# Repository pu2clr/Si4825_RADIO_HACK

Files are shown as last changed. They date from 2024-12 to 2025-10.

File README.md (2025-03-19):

# Si4825 RADIO HACK

This project aims to assist individuals interested in developing or modifying receivers based on the Si4825. It focuses on converting AM/FM radios equipped with the Si4825 DSP to enable shortwave (SW) reception, as well as expanding the shortwave bands on existing AM/FM/SW receivers. By modifying and enhancing the circuitry, this documentation and project provide guidance on expanding the functionality of these radios, allowing them to receive a broader range of frequencies. By understanding the documentation presented in this repository, you are also expected to be capable of developing your own receiver using the Si4825 and a few additional components.

***One of the highlights of this documentation is to unlock new capabilities in receivers based on the Si4825, providing a practical and accessible way to upgrade and customize low-cost AM/FM radios for shortwave listening.*** 

As suggested before, this repository will serve as a guide for the construction, modification, and improvement of Si4825-based receivers, offering insights into hardware adjustments and software tweaks when applicable. ***Some of the modifications presented here will suggest replacing the Si4825 with the Si4827 - essentially the same DSP, but with additional features that allow for the integration of a microcontroller such as the ATmega328 (Arduino), ESP32, ESP8266, STM32, among others***. Integrating a microcontroller into a radio project involving this DSP series can enhance the user interface by adding buttons and a display to control the receiver.

Author: Ricardo Lima Caratti - Jan, 2025

## Summary

1. [Technical Characteristics of the Si4825](https://github.com/pu2clr/Si4825_RADIO_HACK?tab=readme-ov-file#the-si4825-pinout)
2. [Converting a $5 KapBom (K-2019) AM/FM Analog Radio into a Digital and Shortwave Radio](https://github.com/pu2clr/Si4825_RADIO_HACK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)
3. [Converting a $10 KapBom (KA-3196) AM/FM/SW Analog Radio into a Digital Radio with Extended Shortwave Bands]()
4. [Restoring a Motobras RM-PFT73AC Radio (made in Brazil) into a Digital Radio with FM and Enhanced Shortwave Capabilities]()

## ATTENTION

***Any modifications or interventions you make to your radio - including those equipped with the Si4825 DSP - come with the risk of causing irreparable damage. If you decide to attempt any of the procedures described in this project, please understand that you are doing so at your own risk.***

***The author of this project assumes no responsibility for any damage that may occur to your radio as a result of following the instructions or suggestions provided here.***

***Proceed with caution and ensure you are fully aware of the potential consequences before making any modifications.***

***The tests and observations conducted by the author refer to the SI4825-A10 and SI4825-A20 versions.***

## The Si4825 pinout

To build a radio based on the Si4825 or even modify a commercial radio, it is essential to know the functions of its pins. The following figure presents the pin configuration of the Si4825.

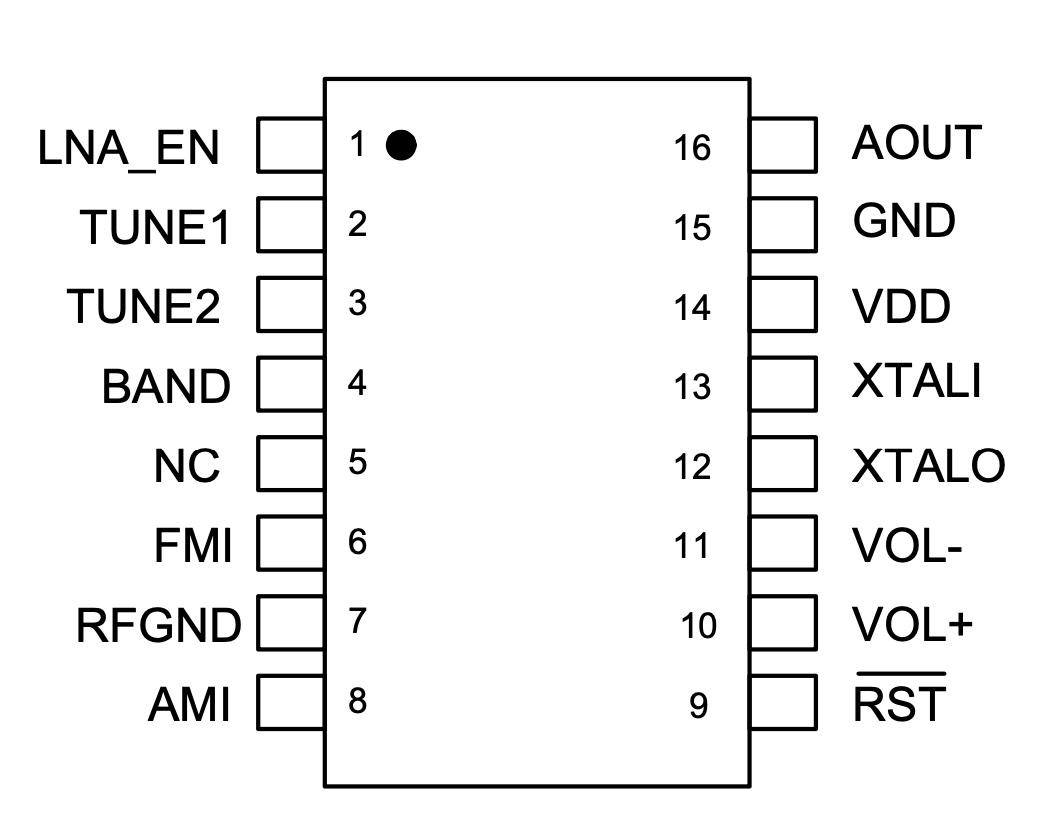
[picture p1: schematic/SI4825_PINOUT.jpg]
The Si4825 pinout


| Pin # | Name | Description |
| ----- | --- | --- |
| 1 | LNA_EN | Enable SW external LNA - Wide or Narrow band - See band table |
| 2 | TUNE1 | Frequency tuning - Connected to the 100K  potentiometer | 
| 3 | TUNE2 | Frequency tuning -  Connected to the 100K  potentiometer |
| 4 | BAND | Band selection -  connected to voltage divider  / band selector |
| 5 | NC | No connect. Leave floating |
| 6 | FMI | FM RF inputs. FMI should be connected to the antenna trace |
| 7 | RFGND | RF ground. Connect to ground plane on PCB |
| 8 | AMI | AM RF input. AMI should be connected to the AM antenna |
| 9 | RST | Device reset (active low) input |
| 10 | VOL+ | Volume button up |
| 11 | VOL- | Volume button down |
| 12 | XTALO | Crystal oscillator output |
| 13 | XTALI | Crystal oscillator input/external reference clock input |
| 14 | VDD | Supply voltage. May be connected directly to battery |
| 15 | GND | Ground. Connect to ground plane on PCB |
| 16 | AOUT | Audio output |

## SI4825 BAND SETUP

The Si4825 is a basic digital AM/FM/SW radio receiver chip that uses mechanical tuning. It handles everything from the antenna input to the audio output, making it a complete radio receiver solution.

This chip is part of Silicon Laboratories' family of multi-band tuners and makes it easier to add radio reception to audio devices. It is small, requires fewer components, and offers proven, high-performance results.

The Si4825 needs only a simple circuit to work and does not require manual tuning during manufacturing. It uses Silicon Labs' patented digital low-intermediate frequency (low-IF) technology, providing good signal reception and interference rejection for AM, FM, and shortwave (SW) bands.

Because the chip is highly integrated and fully tested at the factory, it makes the design process easier, improves overall system quality, and simplifies manufacturing.

**IMPORTANT:** In some contexts within the Si4825 documentation, the acronym AM refers to Medium Wave (MW) rather than Amplitude Modulation. However, it is important to highlight that both MW and SW bands operate using Amplitude Modulation. 

## Frequency Tuning 

A valid channel can be found by adjusting a 100K potentiometer connected to the TUNE1 and TUNE2 pins of the Si4825 chip. The central terminal of the potentiometer is connected to the TUNE2 pin, while the other terminals are connected to TUNE1 and ground, respectively.

This configuration allows for smooth and precise frequency tuning across the supported bands.

### Datasheet FM band information

The Si4825 has a built-in low noise amplifier (LNA) that allows it to receive FM radio signals from 64 to 109 MHz, covering the worldwide FM broadcast band. It can also pick up TV audio stations in the same frequency range used in China.

Pre-emphasis and de-emphasis are techniques used to improve the sound quality of FM radio by reducing high-frequency noise and interference.

When an FM station transmits a signal, it boosts the high audio frequencies using a pre-emphasis filter.
On the receiving end, FM radios use a de-emphasis filter to lower those high frequencies, bringing the sound back to normal.
Different regions use different de-emphasis settings. The de-emphasis filter can have a time constant of 50 or 75 microseconds (µs), depending on the area.

## Datasheet MW(AM) band information 

The Si4825 is a highly integrated radio receiver that can pick up AM (MW) signals from 504 to 1750 kHz across five sub-bands. It uses digital low-IF technology, requiring very few external components and no manual tuning during production.

This technology provides precise filtering, ensuring good selectivity and signal-to-noise ratio (SNR) with minimal variation across the entire AM band. **One of the five sub-bands, called AM4 (520-1730 kHz), is designed to work globally, supporting both 9 kHz and 10 kHz channel spacing to meet different regional AM standards**.

Just like with FM signals, the Si4825 enhances sensitivity and reduces interference from strong signals, making it easier to receive weaker stations.

The receiver is also flexible when it comes to antennas. It works with ferrite loop stick antennas ranging from 180 to 450 µH. If you want to use an air loop antenna, a transformer can be added to increase its inductance. By using a 1:5 turn ratio inductor, the inductance is multiplied by 25 times, making it compatible with most AM air loop antennas, which typically have inductance values between 10 and 20 µH.

## Datasheet SW(AM) information 

The Si4825 can receive signals from 36 shortwave (SW) bands ranging from 2.3 to 28.5 MHz. Of these, 18 bands are narrow meter bands, while the remaining bands cover wider frequency ranges, making them suitable for shortwave radios that operate with one or two SW bands.

The Si4825 offers extensive shortwave capabilities with the advantage of requiring minimal external components and no factory adjustments. Additionally, the FM antenna can be used to receive shortwave signals, simplifying the design and reducing the need for extra components.

### Important Considerations for Shortwave Band Configuration on the Si4825

As shown in the table below, each of the 18 shortwave (SW) bands on the Si4825 can be configured in two modes: **'Wide Band'** or **'Narrow Band'**.  

The values of the resistor network **do not need to be changed** to switch between 'Wide' and 'Narrow'. This configuration is controlled by the state of **pin 1** on the Si4825:  

- If **pin 1** is pulled up to **VCC** using a **10K resistor**, the selected band will be **'Wide'**.  
- If **pin 1** is **floating (disconnected)**, the selected band will be **'Narrow'**.  

As a result, each shortwave band can have **two possible coverage ranges**. See the table below. 

| Band Name  | Band Frequency Range | Channel Space | AR(kΩ)| Note |
| --- | --- | ---| ----- | --- |
| | | | | 47kΩ botton resistor| 
| FM1 | 87-108 MHz (50 µs) | |  47 | | 
| FM2 | 87-108 MHz (50 µs) | |  57 | | 
| FM3 | 87-108 MHz (75 µs) | |  67 | |
| FM4 | 87-108 MHz (75 µs) | |  77 | |
| FM5 | 86.5-109 MHz (50 µs) | |  87 | |
| FM6 | 86.5-109 MHz (50 µs) | |  97 | |
| FM7 | 87.3-108.25 MHz (50 µs) | | 107 | | 
| FM8 | 87.3-108.25 MHz (50 µs) | | 117 | |
| FM9 | 87.3-108.25 MHz (75 µs) | | 127 | |
| FM10 | 87.3-108.25 MHz (75 µs) | | 137 | |
| FM11 | 76-90 MHz (50 µs) | | 147 | |
| FM12 | 76-90 MHz (50 µs) | | 157 | |
| FM13 | 64-87 MHz (50 µs) | | 167 | |
| FM14 | 64-87 MHz (50 µs) | | 177 | |
| FM15 | 76-108 MHz (50 µs) | | 187 | |
| FM16 | 76-108 MHz (50 µs) | | 197 | |
| FM17 | 64-108 MHz (50 µs) | | 207 | |
| FM18 | 64-108 MHz (50 µs) | | 217 | | 
| AM1 | 520-1710 kHz | 10k | 227 | |
| AM2 | 522-1620 kHz | 9k | 237 | |
| AM3 | 504-1665 kHz | 9k | 247 | | 
| AM4 | 522-1728 kHz/520-1730 kHz  | 9k / 10k | 257 | |
| AM5 | 510-1750 kHz | 10k | 267 | |
| SW1-Wide | 2.3-10.0 MHz | 5k | 277 | Pin 1 pulled up | 
| SW1-Narrow | 2.30-2.49 MHz | 5k | | Pin 1 **floating** |
| SW2-Wide | 3.2-7.6 MHz | 5k | 287 | Pin 1 pulled up |
| SW2-Narrow | 3.20-3.40 MHz | 5k | | Pin 1 **floating** | 
| SW3-Wide | 3.2-10.0 MHz | 5k | 297 | Pin 1 pulled up |
| SW3-Narrow | 3.90-4.00 MHz | 5k | | Pin 1 **floating** | 
| SW4-Wide | 3.7-12.5 MHz | 5k | 307 | Pin 1 pulled up | 
| SW4-Narrow | 4.75-5.06 MHz | 5k | | Pin 1 **floating** |
| SW5-Wide | 3.9-7.5 MHz | 5k | 317 | Pin 1 pulled up |
| SW5-Narrow | 5.6-6.4 MHz | 5k | | Pin 1 **floating** | 
| SW6-Wide | 3.2-10.0 MHz | 5k | 327 | Pin 1 pulled up |
| SW6-Narrow | 3.90-4.00 MHz | 5k | | Pin 1 **floating** | 
| SW7-Wide | 5.8-12.1 MHz | 5k | 337 | Pin 1 pulled up | 
| SW7-Narrow | 6.8-7.6 MHz | 5k | | Pin 1 **floating** |
| SW8-Wide | 5.9-9.50 MHz | 5k | 347 | Pin 1 pulled up |
| SW8-Narrow | 7.1-7.6 MHz | 5k | | Pin 1 **floating** | 
| SW9-Wide | 5.9-18.0 MHz | 5k | 357 | Pin 1 pulled up |
| SW9-Narrow | 9.2-10 MHz | 5k | | Pin 1 **floating** | 
| SW10-Wide  | 7.0-16.0 MHz | 5k | 367 | Pin 1 pulled up | 
| SW10-Narrow| 11.45-12.25 MHz | 5k | | Pin 1 **floating** |
| SW11-Wide  | 7.0-23.0 MHz | 5k | 377 | Pin 1 pulled up |
| SW11-Narrow| 11.6-12.2 MHz | 5k | | Pin 1 **floating** | 
| SW12-Wide  | 9.0-16.0 MHz | 5k | 387 | Pin 1 pulled up |
| SW12-Narrow| 13.4-14.2 MHz | 5k | | Pin 1 **floating** | 
| SW13-Wide  | 9.0-22.0 MHz | 5k | 397 | Pin 1 pulled up | 
| SW13-Narrow| 13.57-13.87 MHz | 5k | | Pin 1 **floating** |
| SW14-Wide  | 9.5-18.0 MHz | 5k | 407 | Pin 1 pulled up |
| SW14-Narrow| 15 -15.9 MHz | 5k | | Pin 1 **floating** | 
| SW15-Wide  | 10.0-16.0 MHz | 5k | 417 | Pin 1 pulled up |
| SW15-Narrow| 17.1 -18 MHz | 5k | | Pin 1 **floating** | 
| SW16-Wide  | 10.0-22.0 MHz | 5k | 427 | Pin 1 pulled up | 
| SW16-Narrow| 17.48-17.9 MHz | 5k | | Pin 1 **floating** |
| SW17-Wide  | 13.0-18.0 MHz | 5k | 437 | Pin 1 pulled up |
| SW17-Narrow| 21.2-22 MHz | 5k | | Pin 1 **floating** | 
| SW18-Wide  | 18.0-28.5 MHz | 5k | 447 | Pin 1 pulled up |
| SW18-Narrow| 21.45-21.85 MHz | 5k | | Pin 1 **floating** | 
| | | | 500 | 53kΩ top resistor | 

#### About the Previous Table:

* The **Botton Resistor** (first line - connected to GND) represents the minimum resistance required to reach the first band (FM1). 
* The **Top Resistor** (last line - connected to TUNE1) is the value needed to complete a total of 500K. Hypothetically, if you use all the bands described in the table, you should use a 53K resistor.
* AR(K) is the value of the accumulated resistance required to select the desired band. For example: Consider that the receiver you are designing only includes the SW 10 band. The value of the first resistor (top resistor) should be 367K, and the value of the second resistor (bottom resistor) should be 133K (500 - 367). The common point between the two resistors must be connected to pin 4 of the Si4825 (BAND).
* Pay attention to the SW bands and observe the Wide and Narrow configurations. The resistance value required to select the band does not change. The Wide or Narrow configuration is determined by pin 1 of the Si4825, as previously described.

#### About Narrow and Wide band setup

The Si4825 allows configuration between Wide Band and Narrow Band through pin 1 (LNA_EN). Frequency coverage for Wide and Narrow Band is detailed in the previous table.

In general, Wide Band is recommended when the goal is to provide the user with a broad frequency range, with limited band selection options on the receiver. While this approach allows for shortwave reception over a wide range, it can make locating and tuning to a specific station more challenging. To configure the receiver for Wide Band, simply add a 10kΩ pull-up resistor to the LNA_EN pin.

Conversely, if the radio design includes a multi-position band selection switch (six or more positions, for example), Narrow Band configuration may be more suitable. This option offers narrower coverage bands, providing a more precise tuning experience and making it easier to locate a specific station. For this configuration, the LNA_EN pin should be left floating (unconnected).

It is also possible to implement both options in the same design. To achieve this, add a switch that, when turned on, connects the pull-up resistor to the LNA_EN pin, and when turned off, leaves the pin floating. This will be addressed later with more details.

The images below show the dial examples of commertial receivers based on Si4825 using Narrow and Wide band setup. 

##### Narrow band commertial receiver dial 

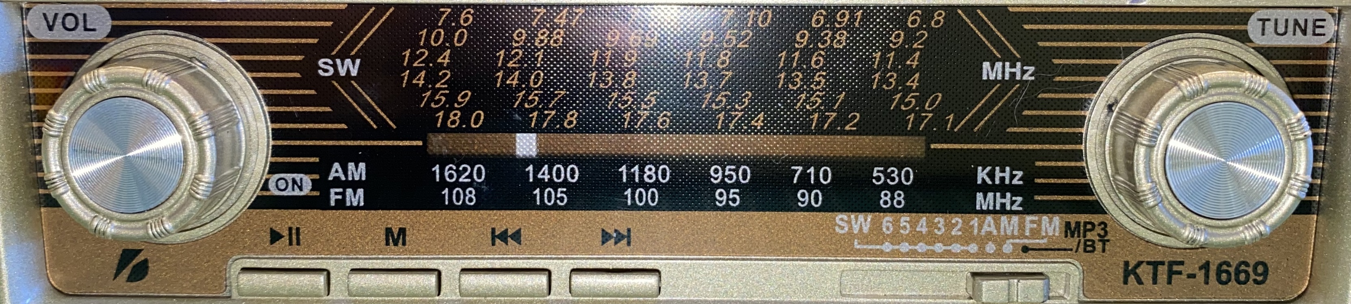
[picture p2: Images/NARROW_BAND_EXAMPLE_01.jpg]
Narrow band commertial receiver dial


Notice in the previous figure that the radio design divides the Shortwave bands into six segments: 6.8 to 7.6 MHz, 9.2 to 10.0 MHz, 11.4 to 12.4 MHz, 13.4 to 14.2 MHz, 15.0 to 15.9 MHz, and 17.1 to 18.0 MHz. This configuration requires a six-position band switch for Shortwave, plus one position for AM/MW and another for FM, totaling eight positions.

This design can provide a better station tuning experience. The narrower bands make it easier to locate and tune to a station compared to a 'Wide Band' design. Additionally, nearby stations broadcasting at the same time are easier to separate.

##### Wide band commertial receiver dial 

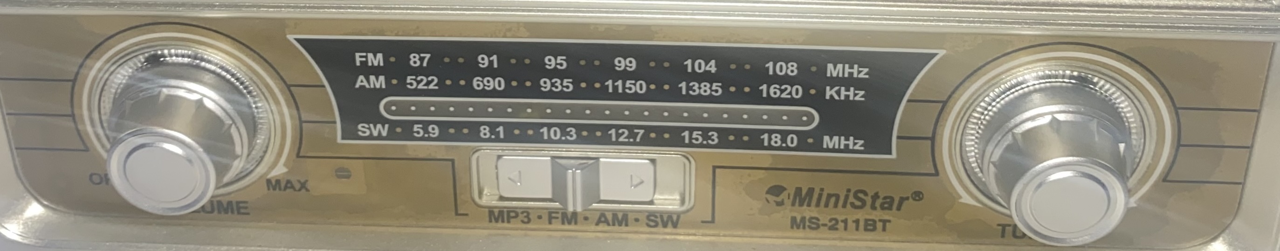
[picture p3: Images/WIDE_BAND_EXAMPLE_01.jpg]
Wide band commertial receiver dial


Notice on the dial shown in the previous figure that a single SW band covers from 5.9 to 18 MHz. This characteristic simplifies, to some extent, the radio design when adding the Shortwave band. However, this configuration may make it more difficult to tune stations, especially if the user wants to tune in to a station located among others nearby.

#### The circuit below shows the Narrow and Wide Band setup.  

Although not very common or typically found in commercial receivers based on the Si4825, it is possible to build a receiver that offers Narrow and Wide Band options. To achieve this, simply follow the circuit shown below.

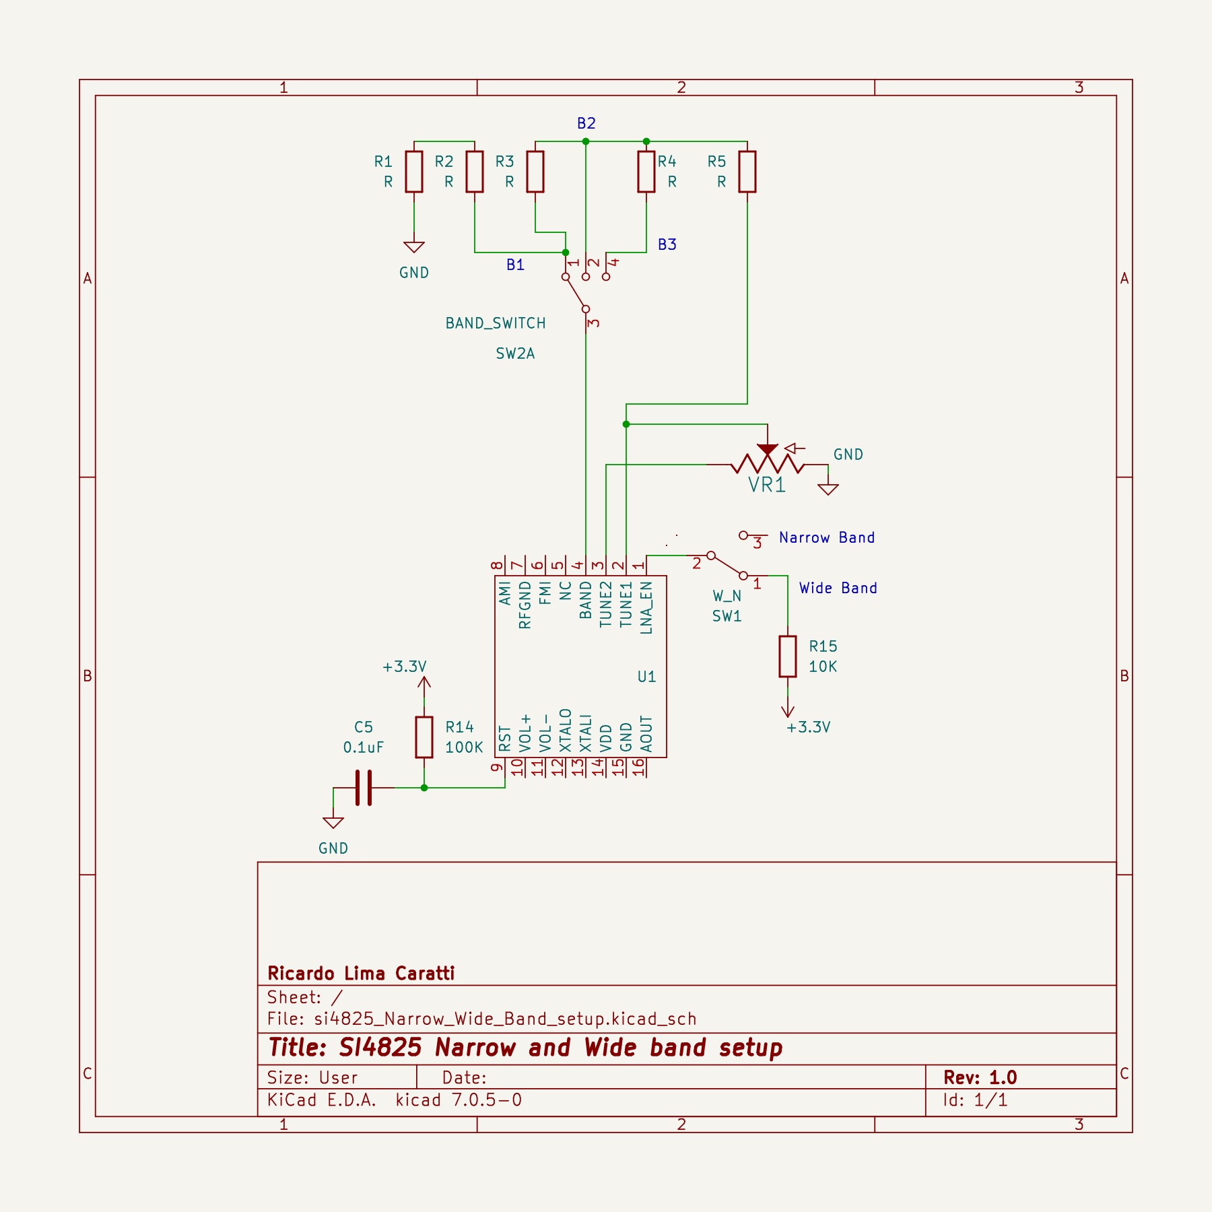
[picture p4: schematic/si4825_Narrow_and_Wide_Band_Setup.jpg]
About Narrow and Wide band setup


However, if you incorporate the previously mentioned tip regarding the Narrow and Wide Band configuration into the circuit, you can opt for 24 shortwave bands instead of 12. 

***Note: Changing the state of this switch does not immediately alter the configuration from Wide to Narrow (or vice-versa). For the change to take effect, the Si4825 must be reset or power-cycled.***

#### More About Pin 1 (LNA_EN) 

Under normal conditions, this pin stays in a high state (+Vcc) when the selected band is Shortwave. This behavior can be used for purposes beyond those previously mentioned (activating a signal amplifier or switching between Narrow and Wide band). A simple function for this pin could be to light up an LED, indicating to the user that the radio is operating in Shortwave mode. Another use is to activate a bandpass filter for Shortwave or switch the antenna when a Shortwave band is selected.

#### Band Allocation Plan for a hypothetical 12-Position Band Selector example

Development of a band allocation plan for a 12-position selector, designed to control a receiver based on the Si4825. The plan segments the spectrum into 12 bands, covering one FM band, one AM band, and ten Shortwave (SW) bands. The band definition aims to optimize signal reception, ensuring comprehensive coverage of radio frequency ranges, with a focus on maximizing the device's selectivity.

The table below shows the Band Allocation Plan for a 12-Position Band Selector (12 Bands - One FM Band, One AM Band, and Ten Shortwave Bands) for the Si4825. The highlights in Blue, Red, and Green represent the bands selected for implementation in the hypothetical radio.

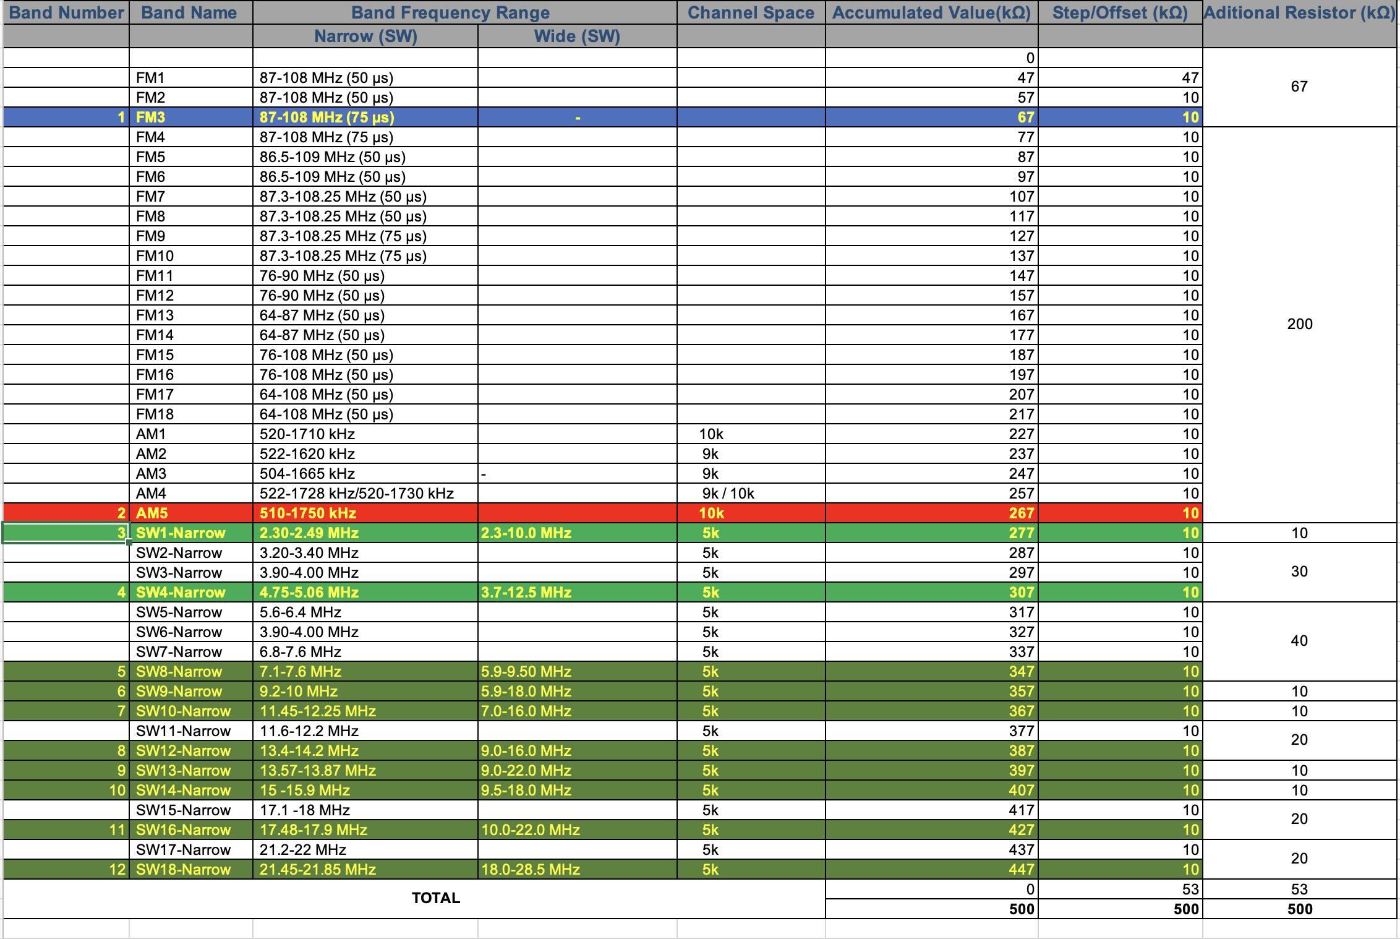
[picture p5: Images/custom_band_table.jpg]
Band Allocation Plan for a 12-Position Band Selector example


The circuit below illustrates the implementation of a theoretical 12-position band selector.  

##### Si4825 Band circuit setup Example

The following example illustrates the band configuration for a hypothetical 12-band radio, one FM band, one MW(AM) band, and 10 SW bands. Observe in the circuit the indication of the band name (according to the previous table), the applied resistors, and the accumulated resistance value. ***It is important to highlight that for this hypothetical project, pin 1 of the Si4825 is not in the pull-up configuration. Thus, all selected SW bands will be 'Narrow'.***

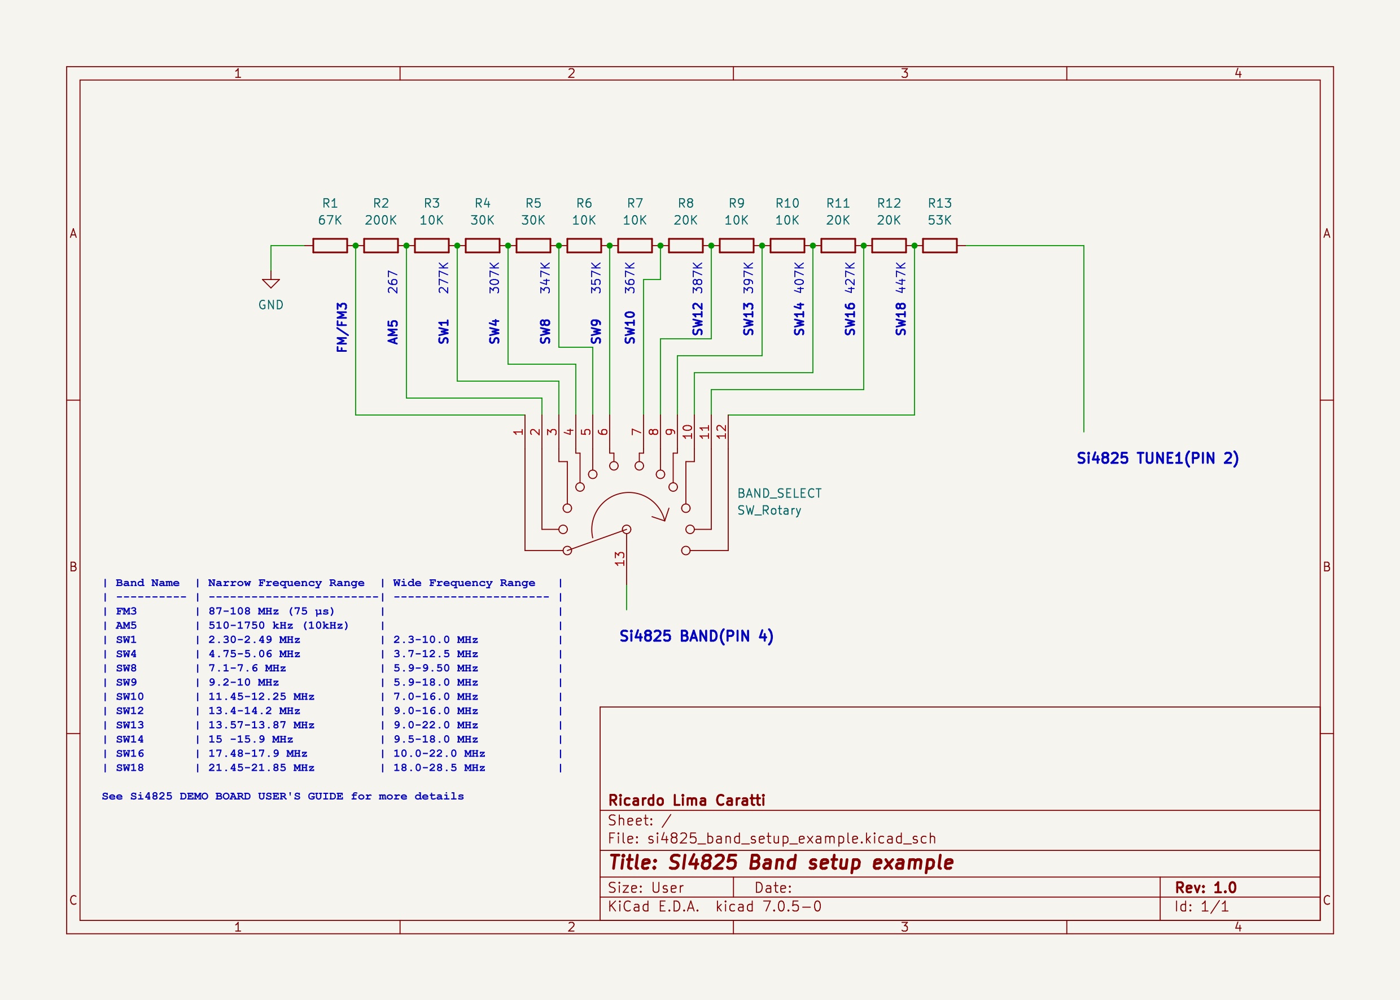
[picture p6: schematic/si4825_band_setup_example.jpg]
Si4825 Band setup Example


## Examplo 1 - Modifying a Low-Cost AM/FM Radio to Receive Shortwave

In this example, a small modification will be made to a low-cost radio (priced at $5 or less), based on the Si4825, with only two band options (AM/MW and FM). The image below shows the radio.

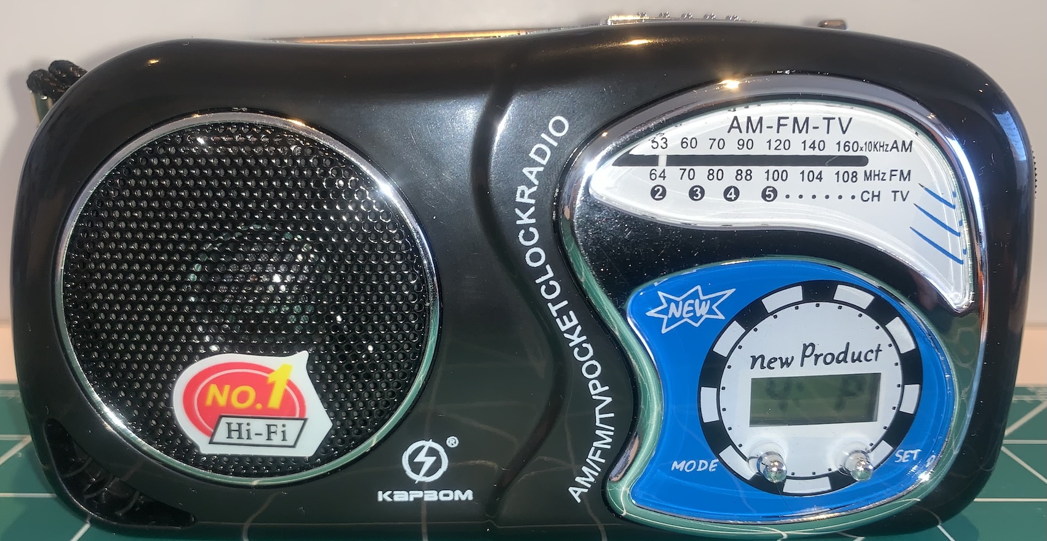
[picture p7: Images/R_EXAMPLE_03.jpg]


The image below shows the radio opened, with the top part of the circuit board featuring very few components - a characteristic of DSP-based receivers, including the Si4825.

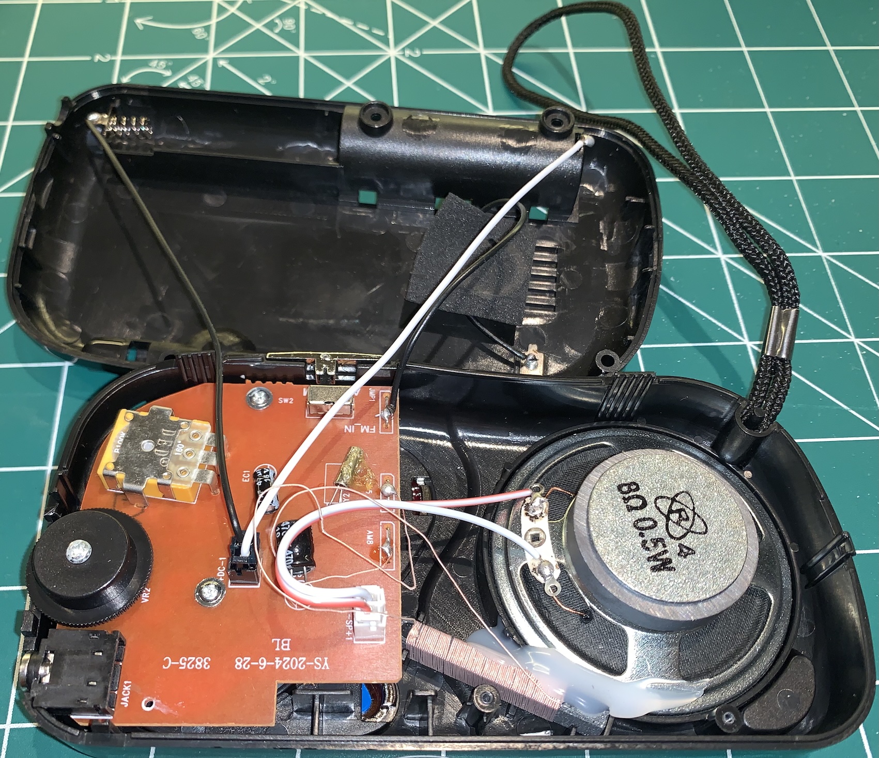
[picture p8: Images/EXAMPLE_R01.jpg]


The image below shows the bottom part of the circuit board, where the DSP Integrated Circuit (likely the Si4825) can be located. Why "likely"? Well, it is common for receivers with the same appearance to be equipped with other DSPs competing with the Si4825.

To confirm that it is indeed the Si4825, it is necessary to identify the connections between the IC and the tuning potentiometer (pins 2 and 3), the band selection pin (pin 4), the pins where the crystal is connected (pins 12 and 13), the AM antenna (pin 8 - AMI), and the FM antenna (pin 6 - FMI). It is unlikely that an IC from another manufacturer will have the same pin configuration.

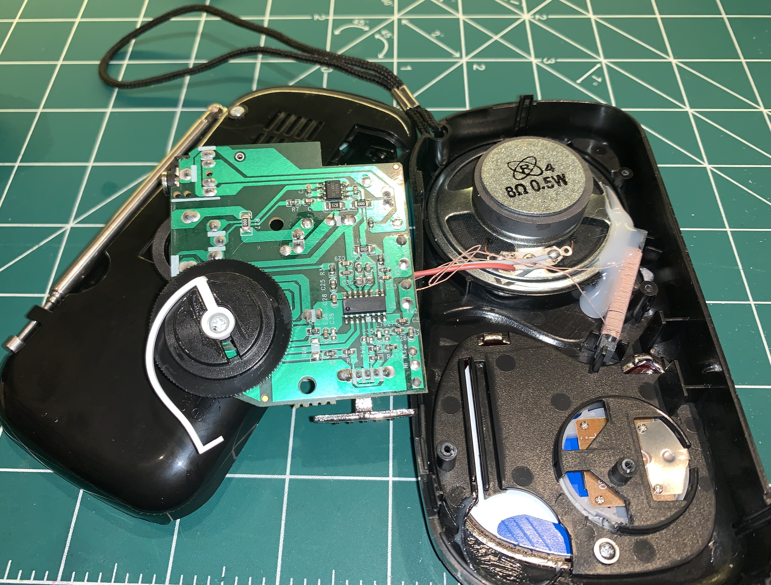
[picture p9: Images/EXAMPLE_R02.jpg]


In the figure below, note the red highlights. These indicate the points where the modification will be made. Essentially, the modification involves removing the resistors responsible for selecting the AM and FM bands.

Notice that there is a two-position switch that allows for this selection. The center point of the switch is connected to pin 4 of the IC, indicating that it is a Si4825. To confirm, observe the connections to the tuning potentiometer.

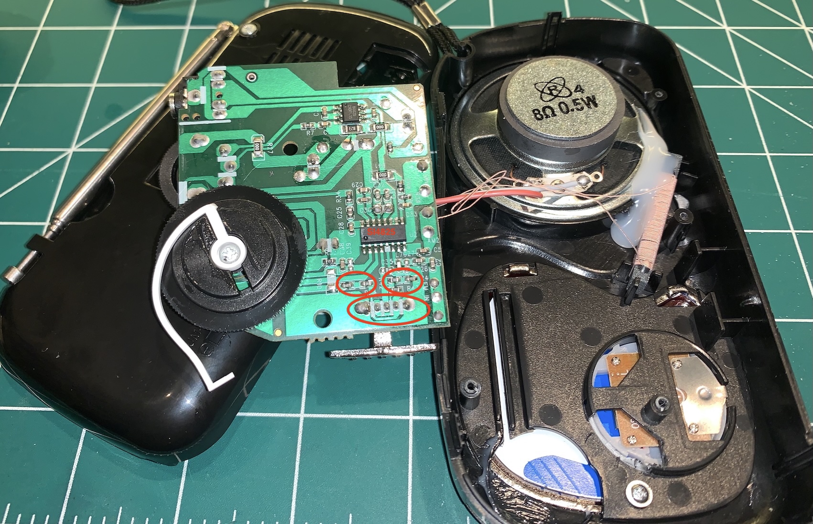
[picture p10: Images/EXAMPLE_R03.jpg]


In a closer view, note that the IC has been scraped by the manufacturer. This highlights the importance of knowing the Si4825 pin configuration as well as understanding the connections of external components to the IC.

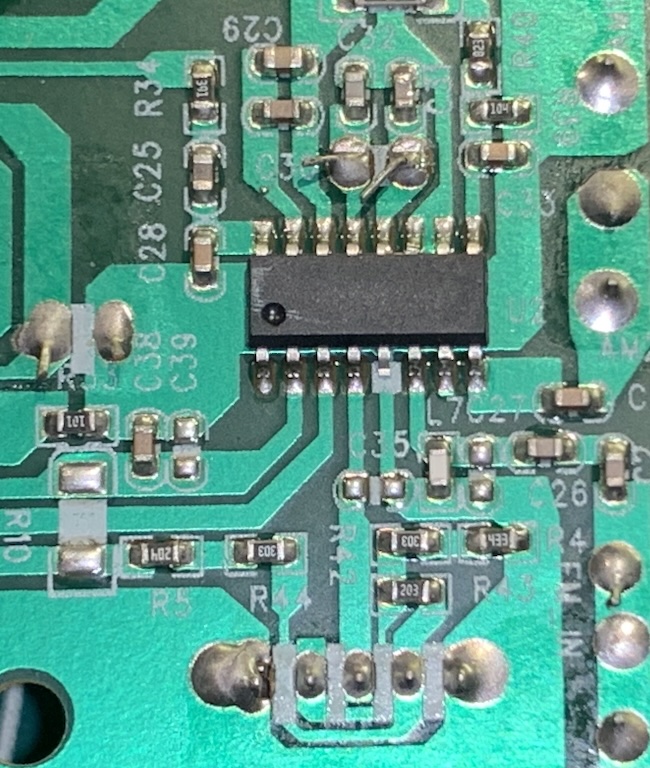
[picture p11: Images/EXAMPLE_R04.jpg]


In the image below, note the red highlights indicating the removal of the original band selection resistors, as well as the removal of the original band switch.

***Note: Depending on the modification to be made, removing the original switch may not be necessary.***

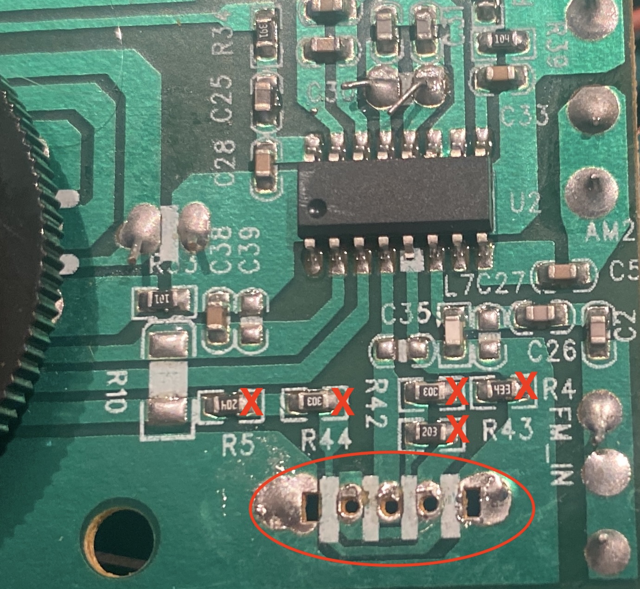
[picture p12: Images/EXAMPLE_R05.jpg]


The figure below shows the new "band selector" for the radio. In reality, it is a 1M potentiometer, but ideally, it should be a 500K potentiometer.

Remember that, as previously mentioned, the resistor network (voltage divider) for band selection should be 500K, according to the manufacturer. Since it is a voltage divider, using a 1M potentiometer for this purpose did not seem to cause any issues.

In the configuration shown in the image, the receiver will cover all the Narrow bands available on the Si4825.

The challenge with this approach - using a variable resistor instead of a band switch - is that locating the desired band becomes more difficult, as there is no precise indication of the resistance or the voltage divider result on the potentiometer. However, with experience using the radio in this configuration, it becomes easier to find a particular band and, consequently, a shortwave station.

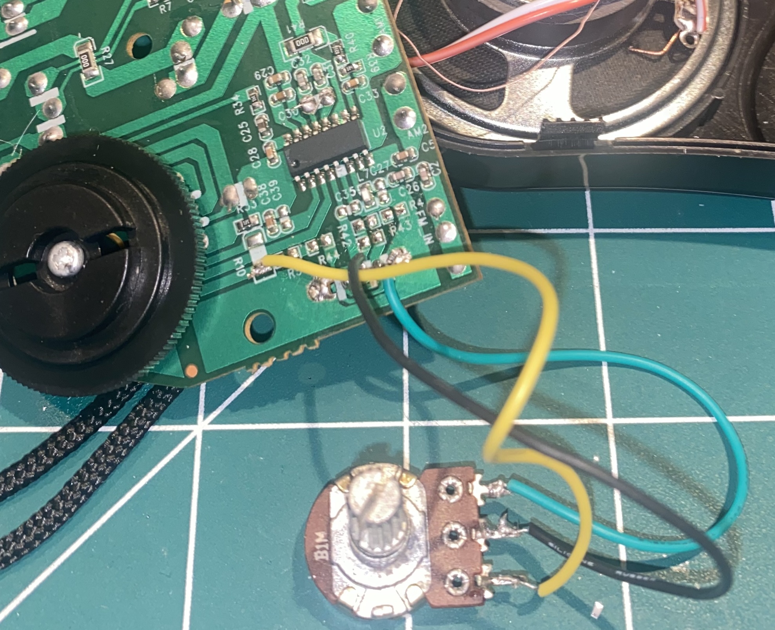
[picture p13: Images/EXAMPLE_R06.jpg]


The figure below illustrates the final result of the modification. There is a [video on YouTube](https://youtu.be/3q1Z5tCHIJM?si=PKrBP-vTaTvmAvGj) (in Portuguese) that showcases some shortwave receptions using this radio. Link to the vídeo: https://youtu.be/3q1Z5tCHIJM?si=PKrBP-vTaTvmAvGj

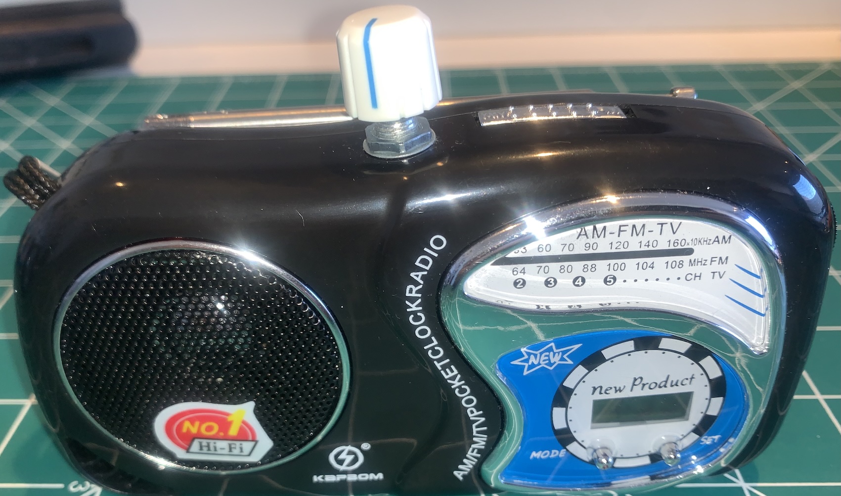
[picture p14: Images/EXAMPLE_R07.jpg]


***It is essential to analyze the front-end of the radio being modified, including the antenna, band-pass filters, and other components. Some commercial receivers, even low-cost ones, may use some form of signal processing at the RF input. This means that, in certain cases, signals within specific frequency ranges may be filtered, preventing adequate reception of certain bands.***

***In the case of the receiver presented in this example, such filtering does not occur. However, if you encounter difficulties tuning to Shortwave stations in certain bands, it is recommended to inspect the AMI (AM Input) and FMI (FM Input) circuits. If necessary, consider modifying these circuits to resemble the model suggested in the Si4825 datasheet.***

## Examplo 2 - Improving a Low-Cost AM/FM Radio to Receive Shortwave from 2.3 to 28.5 MHZ with digital interface

This experiment consists of using the same radio presented in the previous section and transforming it into a multi-band radio with a digital interface through a microcontroller, buttons, and an OLED display. 

For this, it will be necessary to replace the Si4825 with an Si4827, connect it to an Arduino microcontroller or a similar device, and display some information on a small OLED screen.

The following photo shows the final result of the modification.

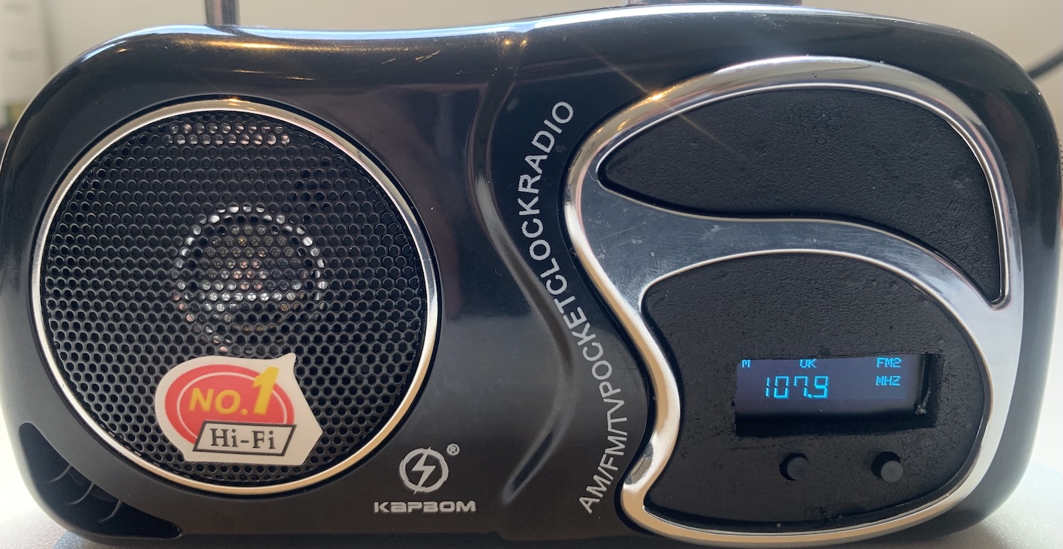
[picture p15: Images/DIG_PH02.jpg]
Final result of the modification


The components needed to make the modification 

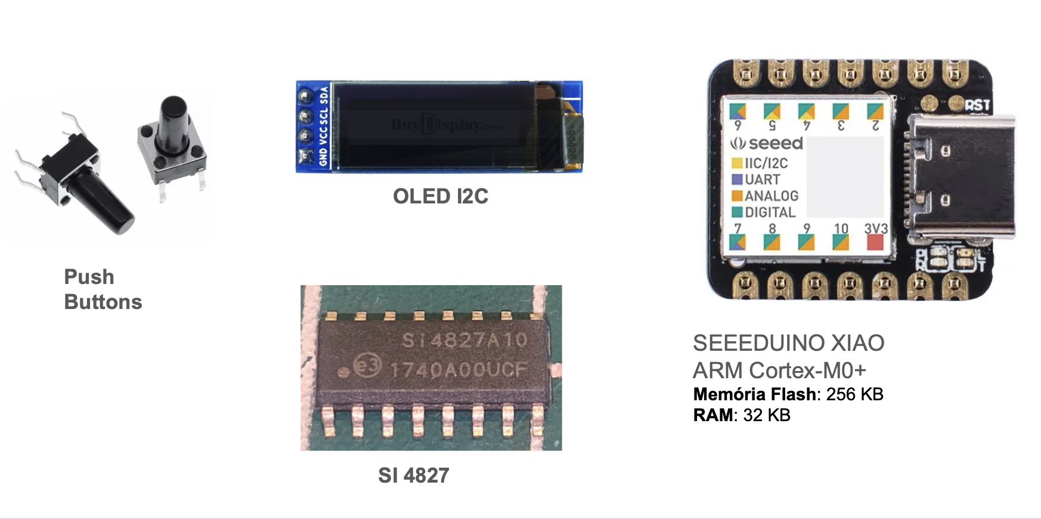
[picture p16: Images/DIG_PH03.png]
Components


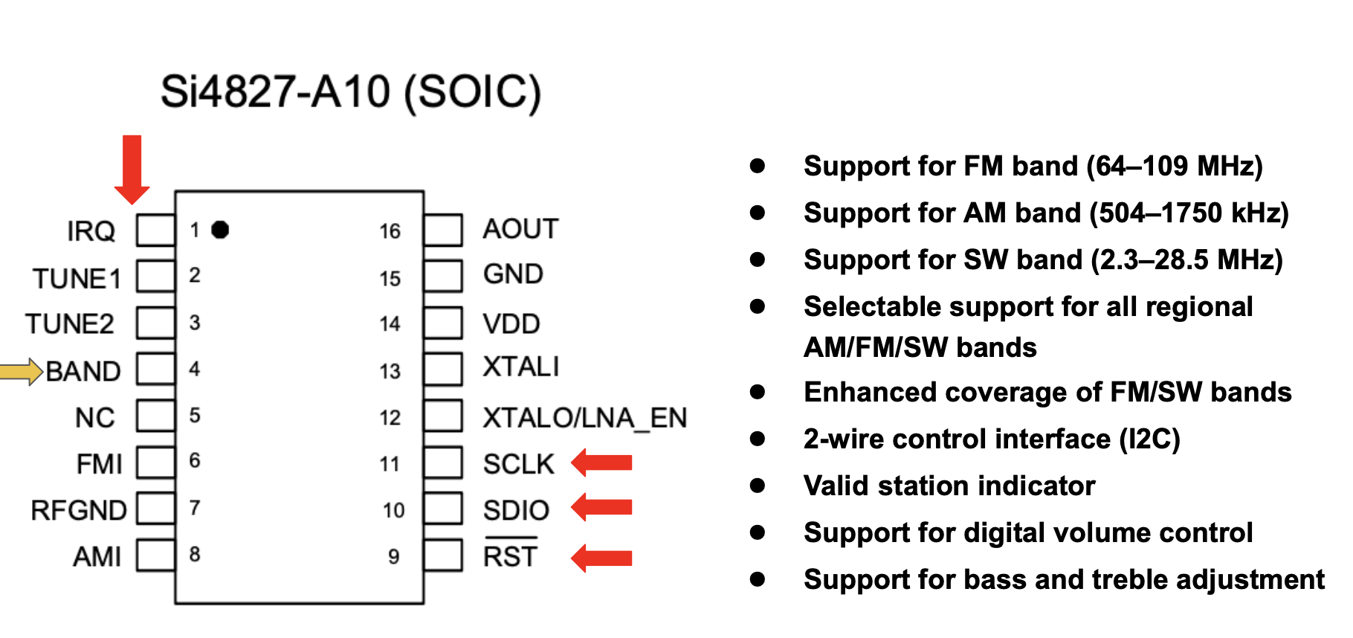
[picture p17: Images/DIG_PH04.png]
Si4827 Pinout


[See more about this modification...](https://github.com/pu2clr/Si4825_RADIO_HACK/tree/main/Transformation/KAPBOM_K2019)

## References 

* BROADCAST MECHANICAL TUNING AM/FM/SW RADIO RECEIVER (Si4825)
* SKYWORKS -  Si4825 DEMO BOARD USER'S GUIDE (Si4825-DEMO)
* [DIY Si4825 A10 multiband Radio MW,SW,FM](https://youtu.be/gH5_U2VM6XY?si=lhl02nU1OgIUE2gD)
* [MAKING A MODERN RADIO](https://www.nutsvolts.com/magazine/article/june2013_OpenCommunication)
* [A Voltage Controlled Multi-Band Radio Synth Module using the Si4825](https://balmatronics.wordpress.com/2021/01/28/a-voltage-controlled-multi-band-radio-synth-module-using-the-si4825/)
* [RECEPTOR FM/OM/SW(AM) com SI4825](https://www.qsl.net/py2ohh/trx/si4825/si4825.html)

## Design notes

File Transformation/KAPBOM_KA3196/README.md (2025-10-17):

# Modifying the KapBom KA3196 Radio

## Slide 1

### Converting the KAPBOM KA-3196 radio (based on the Si4825 DSP) into a radio with a digital interface using the Si4827 DSP.

#### The Original Radio

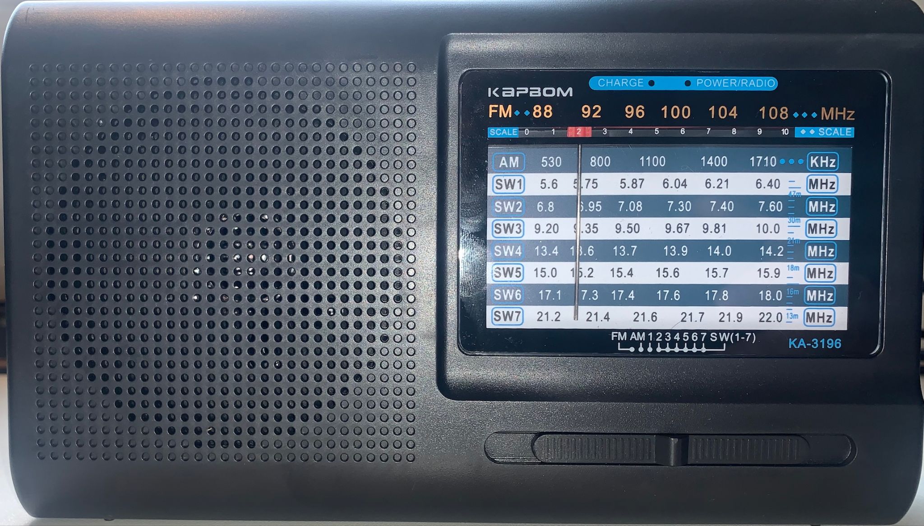
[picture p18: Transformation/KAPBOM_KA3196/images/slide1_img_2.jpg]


#### The Modified Radio

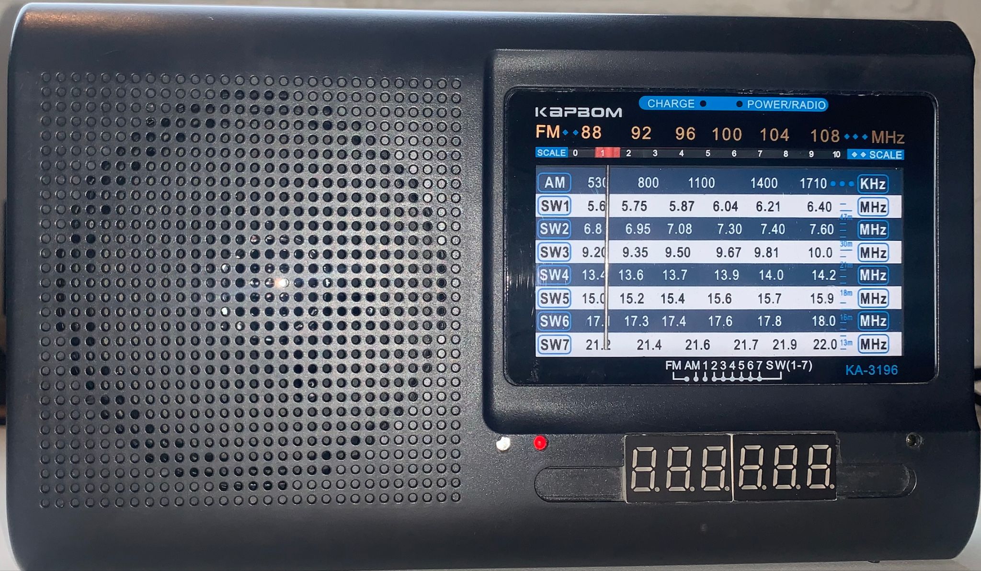
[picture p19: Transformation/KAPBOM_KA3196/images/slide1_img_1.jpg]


---

## Slide 2

### About the KapBom KA3196 Radio (Original)

- Price: $10 to $15

- 9 bands (FM, AM and 7 SW)

- Shortwave coverage: 62m, 49m, 41m, 31m, 16m and 13m

- RF signal amplifier for SW

- Analog dial

- Based on the Si4825 DSP

- Good sound quality

- Classic vintage radio design

- Rechargeable battery (USB) and optional two D-size cells

- No extended FM

- No 25m SW band (11,600 to 12,200 kHz)

- No accessories (radio only)

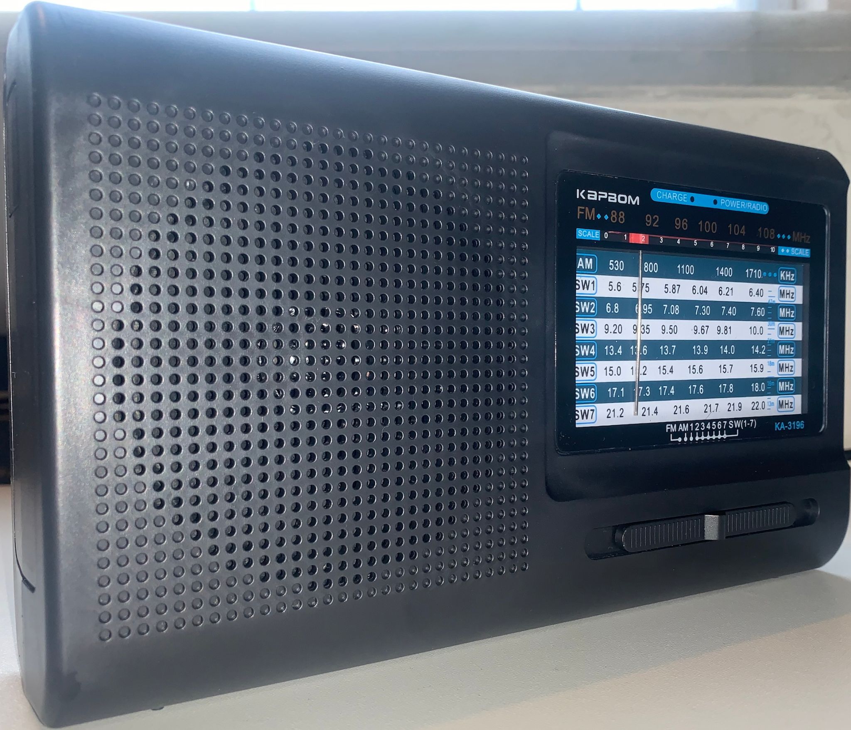
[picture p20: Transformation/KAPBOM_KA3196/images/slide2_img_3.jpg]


---

## Slide 3

### About the KapBom KA3196 Radio (Modified)

- Retains all basic features of the original radio

- 19 bands (2 FM, 2 AM and 15 SW)

- Shortwave coverage: 10m–90m (15 bands)

- User can enable or disable the RF signal amplifier

- Analog and digital dial

- Based on the Si4827 DSP

- Tuned station indicator

- Indicator showing match between analog dial and digital display

- RF amplifier enabled indicator

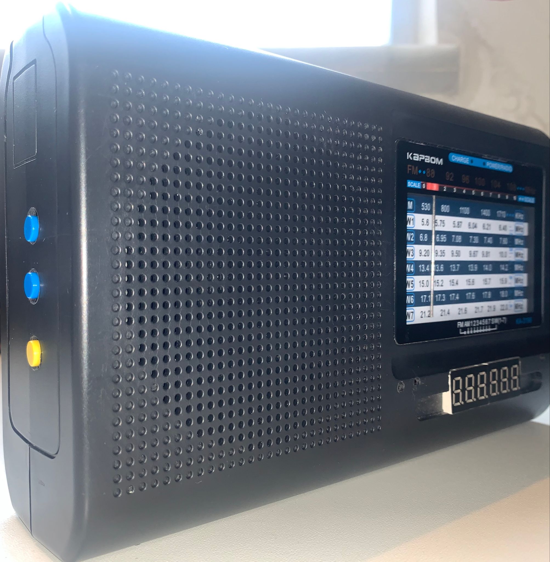
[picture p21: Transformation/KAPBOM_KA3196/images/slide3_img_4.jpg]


---

## Slide 4

### Original radio opened

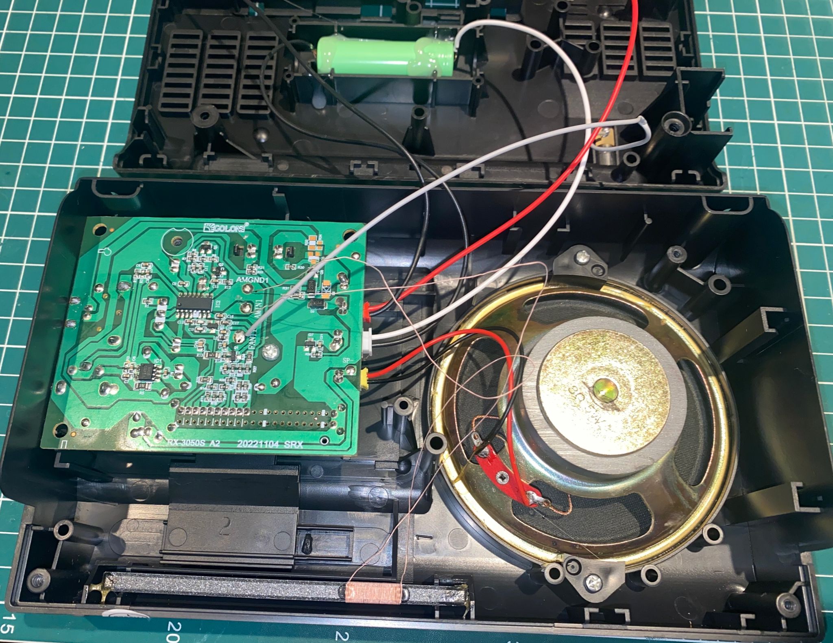
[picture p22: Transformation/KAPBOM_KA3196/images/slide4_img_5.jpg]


---

## Slide 5

### Replacement of Si4825 with Si4827

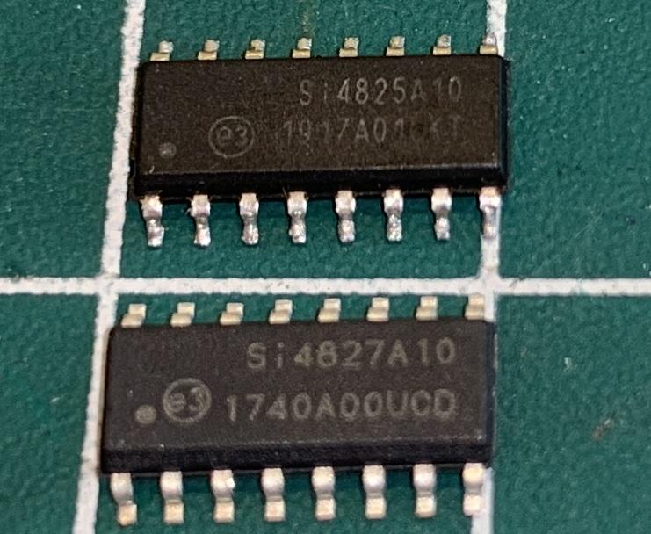
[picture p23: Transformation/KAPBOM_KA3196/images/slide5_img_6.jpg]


---

## Slide 6

### Si4825 vs Si4827 DSP

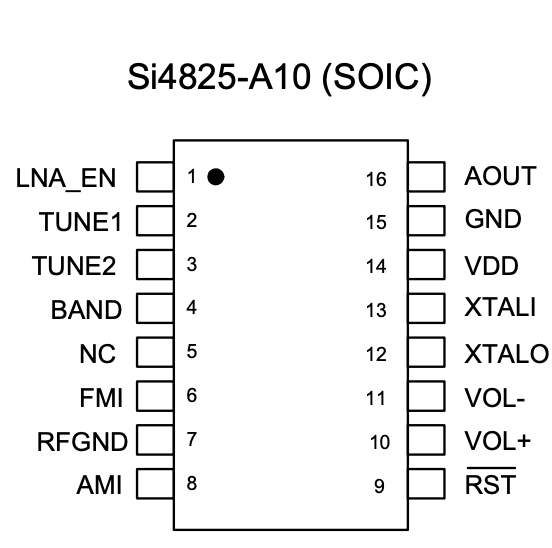
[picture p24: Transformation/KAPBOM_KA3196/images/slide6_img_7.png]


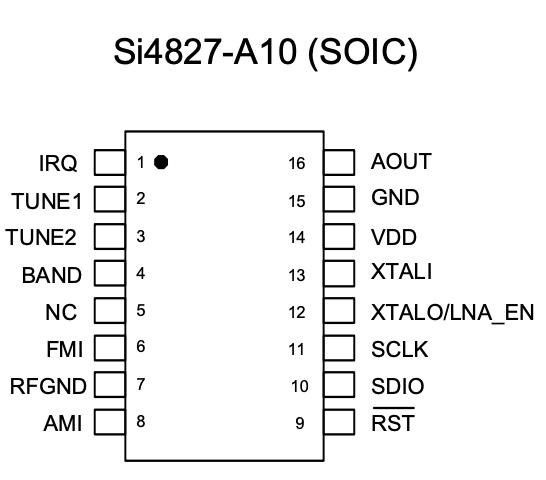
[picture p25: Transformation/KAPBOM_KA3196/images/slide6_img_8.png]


---

## Slide 7

### KapBom radio PCB with Si4825

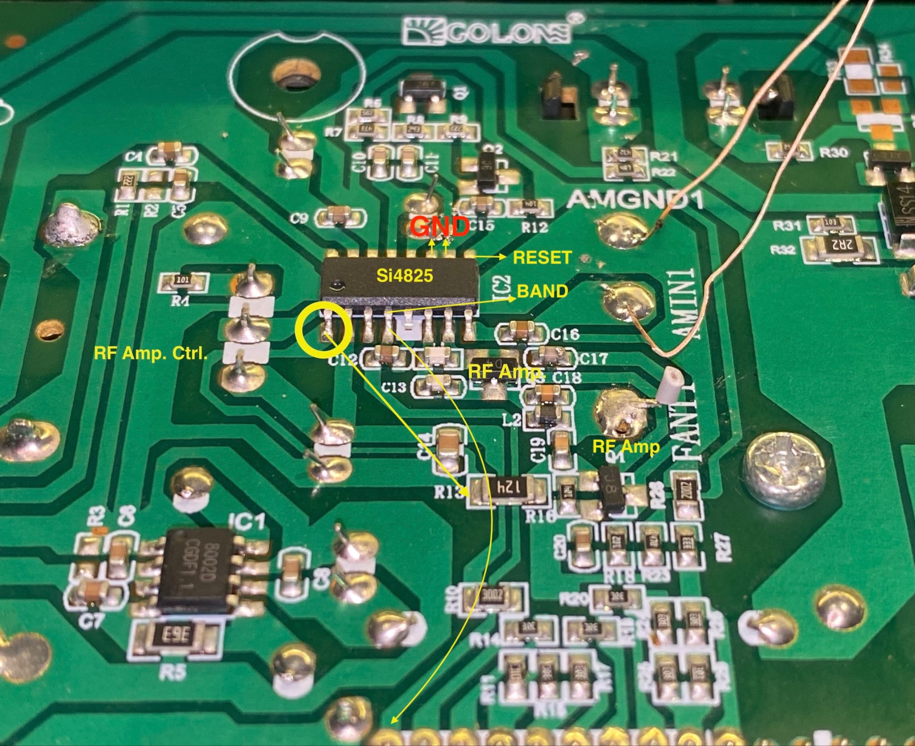
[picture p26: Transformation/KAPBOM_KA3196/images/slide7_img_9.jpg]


---

## Slide 8

### Removal of Si4825

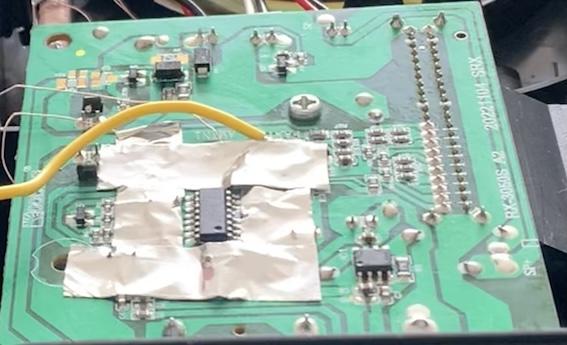
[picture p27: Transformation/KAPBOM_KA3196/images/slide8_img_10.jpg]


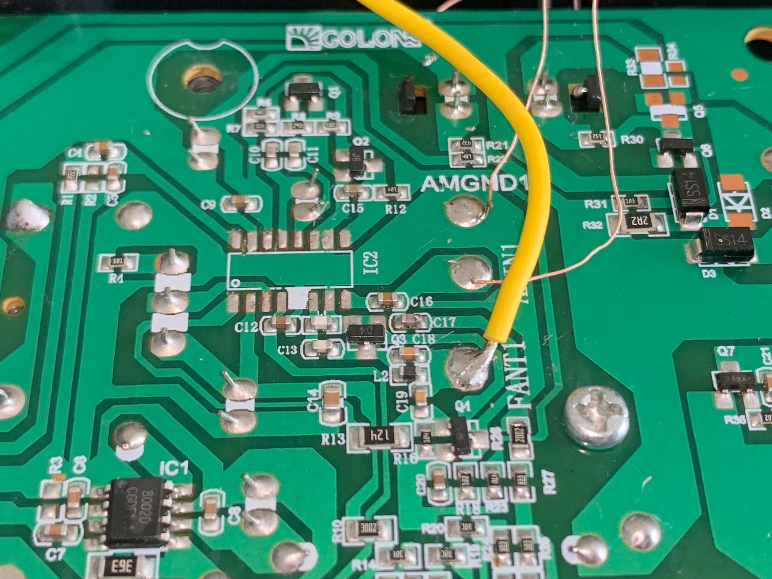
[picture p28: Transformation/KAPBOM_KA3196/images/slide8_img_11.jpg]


---

## Slide 9

### Preparation for Si4827

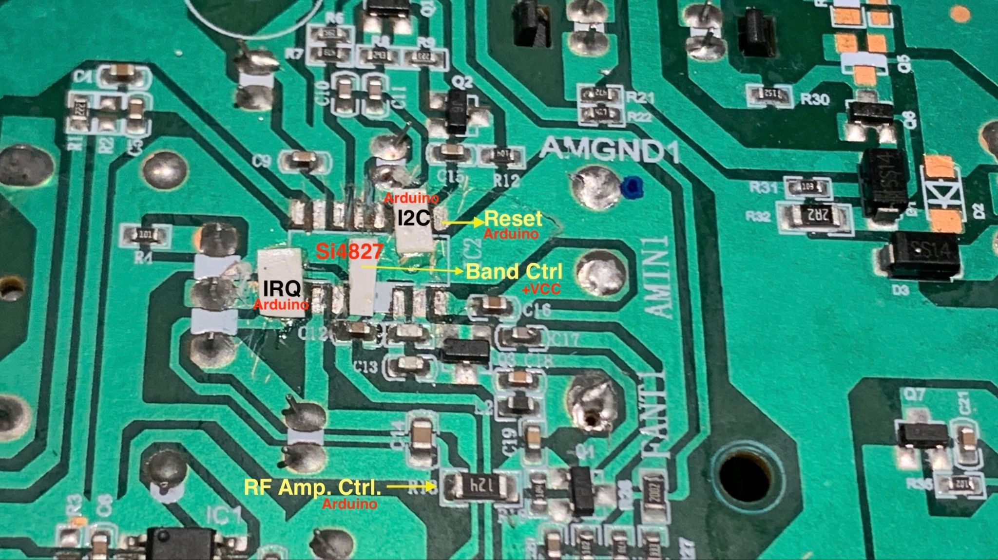
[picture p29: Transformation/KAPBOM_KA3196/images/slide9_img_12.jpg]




---

## Slide 10

### Signal amplifier

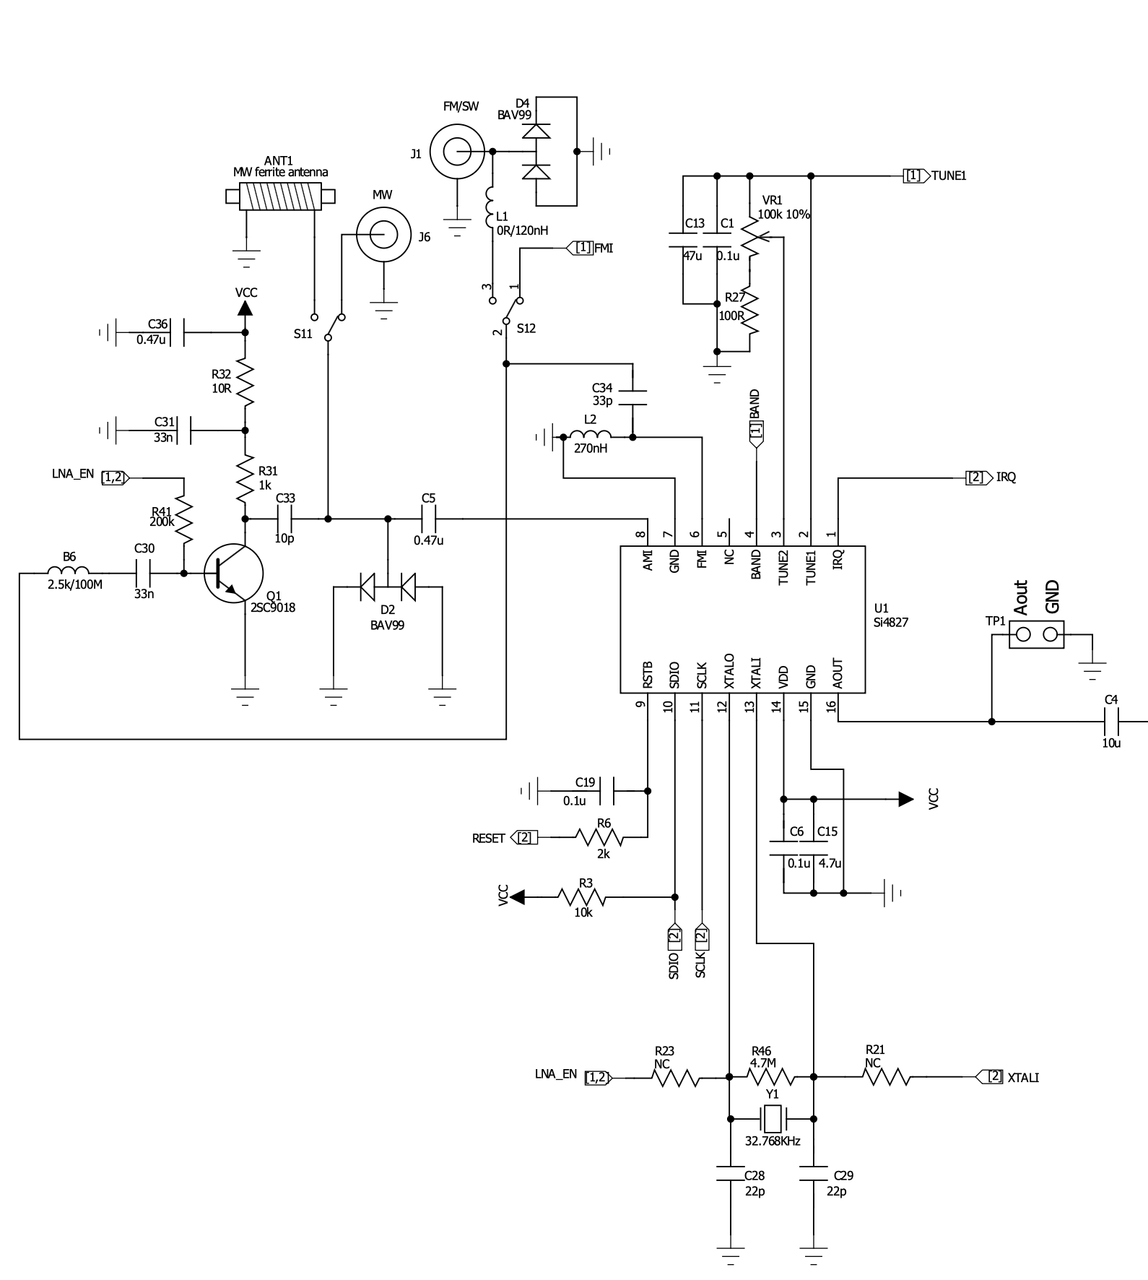
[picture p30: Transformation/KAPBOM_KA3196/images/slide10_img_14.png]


---

## Slide 11

### Components for the modification

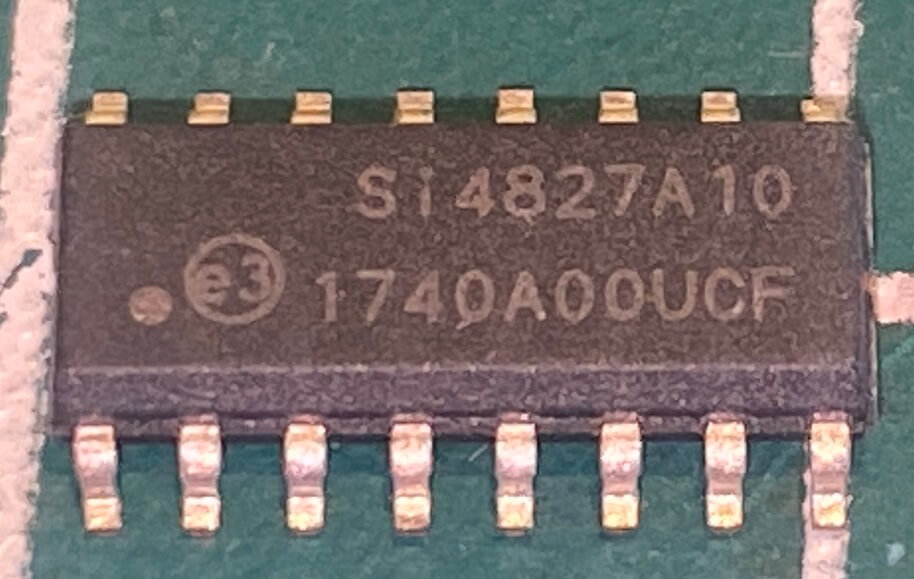
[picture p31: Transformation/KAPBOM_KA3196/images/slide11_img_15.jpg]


- TM1637 7-seg display

- Si4827

- Push buttons

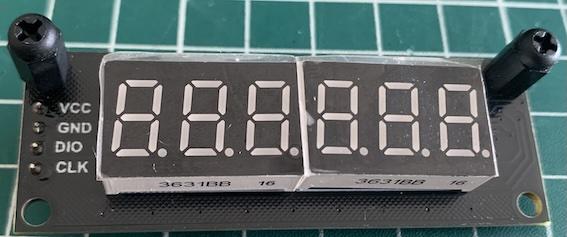
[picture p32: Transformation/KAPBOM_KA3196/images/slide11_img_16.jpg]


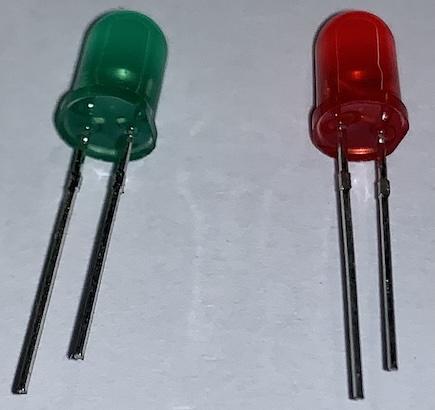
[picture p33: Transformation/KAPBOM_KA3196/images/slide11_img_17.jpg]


- LEDs

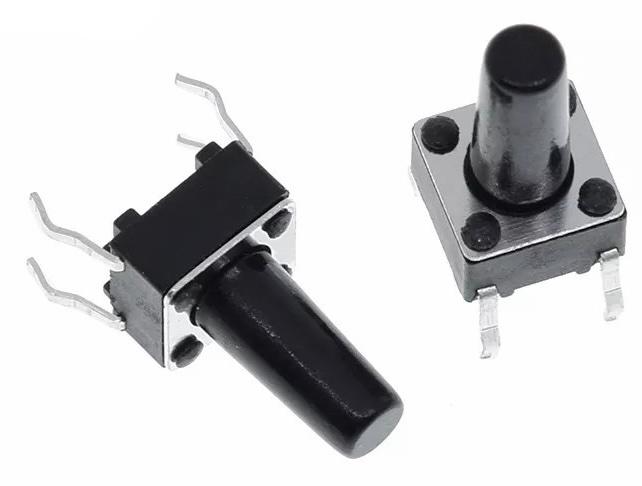
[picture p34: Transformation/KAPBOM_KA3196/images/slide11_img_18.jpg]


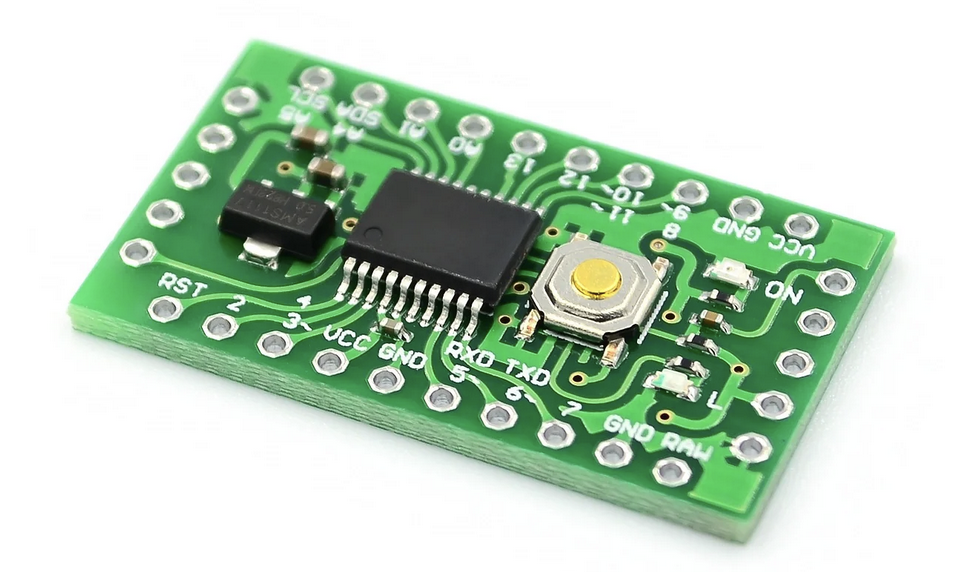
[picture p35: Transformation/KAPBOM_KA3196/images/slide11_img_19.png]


- LGT8F328

- Compatible with Arduino Pro Mini

---

## Slide 12

### Connections of components to Arduino / LGT8F328

---

## Slide 13

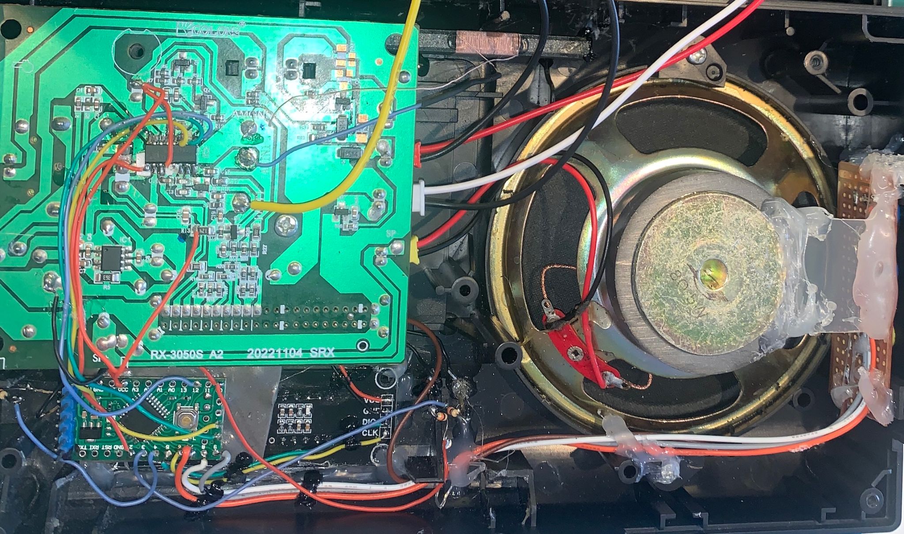
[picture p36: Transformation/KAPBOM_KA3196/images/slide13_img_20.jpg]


---

## Slide 14

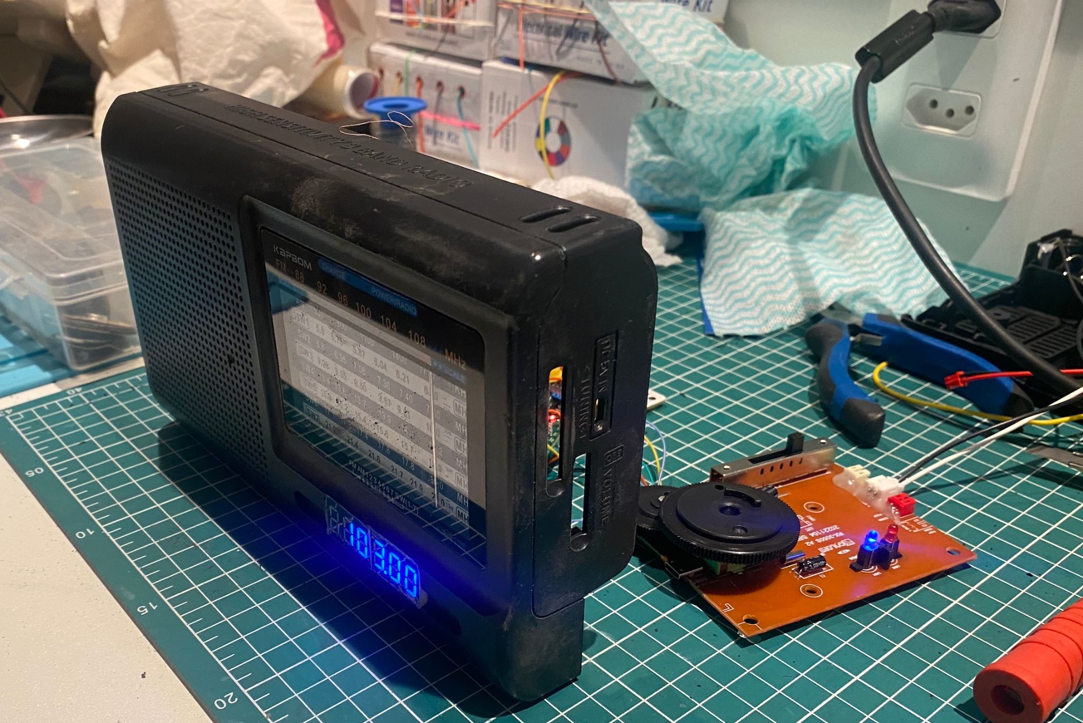
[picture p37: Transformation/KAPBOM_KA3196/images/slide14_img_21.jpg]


---

## Slide 15

### Modification completed





---

##  Arduino and Si4827 pin connections
| SI4827 pin | Arduino pin |  Description |
| ---  | ---  | ---  |
| 1 |  D2 | Arduino interrupt pin |
| 9 |  D12 | RESET |
| 10 |  A4/D4 (SDA)  | I2C bus (Data) |
| 11 |  A5/D5 (SCL)  | I2C bus (Clock) | 
| -----------| ------------- | ---------------------------------------------------|
|  TM1637 | |  7 Seg. Display based on TM1637 |
| -----------| ------------- | ---------------------------------------------------| 
| Data |  5 | |
| CLOCK |  6 | | 
| -----------| ------------- | ---------------------------------------------------|
|Push Buttons| | |
| -----------| ------------- | ---------------------------------------------------| 
|  BAND_UP | 7 | Next Band | 
|  BAND_DOWN | 8 | Previous Band | 
|  SW LNA_EN | 9 | Enable/Disable LNA for Shortwave | 
| -----------| ------------- | ---------------------------------------------------| 
|  LEDs | | |
| -----------| ------------- | ---------------------------------------------------| 
|  DIAL | 3 | Indicates that the analog dial shows the current frequency, matching the one displayed on the screen |
|  TUNE | 4 | Indicates that the receiver is tuned in a valid channel |
|  LNA EN | 10 | Shares the same Arduino/LGT pin 9 to indicate that the LNA is enabled |

__See Arduino folder and check the sketch of this projetct__

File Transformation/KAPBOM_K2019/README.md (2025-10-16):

# Converting Si4825 to Si4827 with Digital Interface

## Slide 1

### Converting a low-cost radio based on the Si4825 into a digital interface radio using the Si4827.

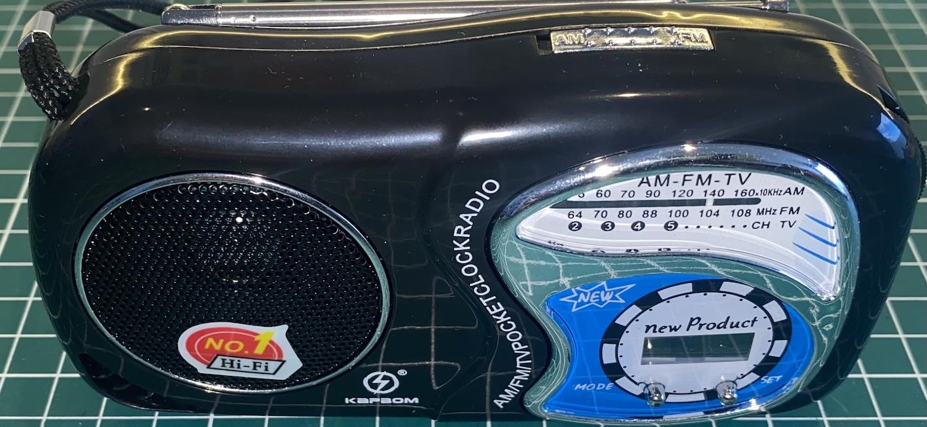
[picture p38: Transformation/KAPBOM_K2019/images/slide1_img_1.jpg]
Slide 1 image

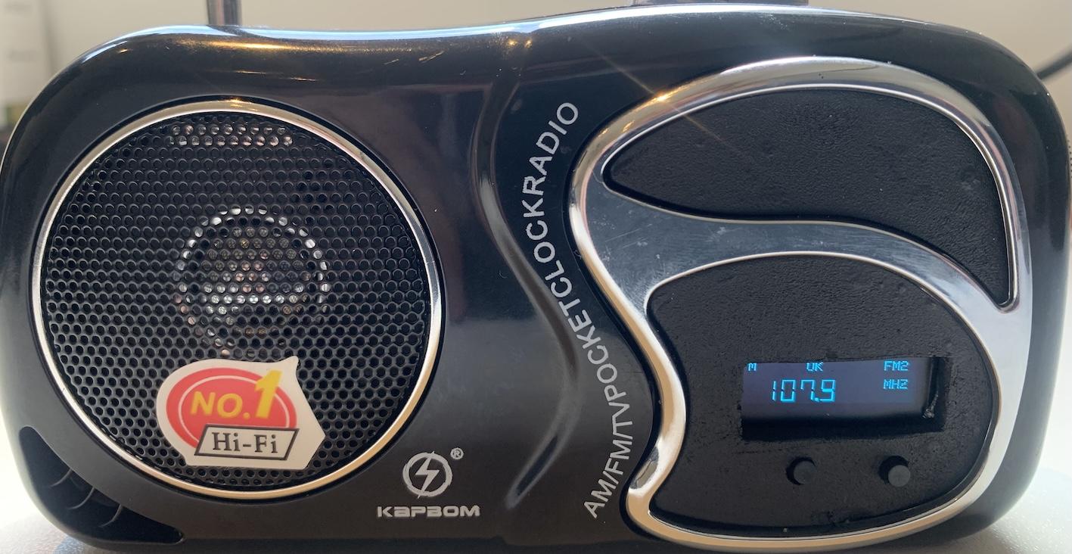
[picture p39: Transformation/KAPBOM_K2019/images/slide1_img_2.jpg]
Slide 1 image


---

## Slide 2 — About the low-cost radio (KapBom K2019)

- Two bands (MW and FM)
- Less than $5
- Compact and lightweight
- Based on the Si4825 DSP
- Sturdy plastic casing
- Analog interface



- Warning: There are other receivers from different manufacturers that use the same casing but are not equipped with the Si4825. Be sure the receiver is equipped with the Si4825.

---

## Slide 3 — About the modified radio

- 15 bands (3 FM, 2 AM, and 10 SW)
- Bands can be configured via programming
- Based on the Si4827 DSP
- Uses the Seeeduino XIAO controller (ARM Cortex-M0+)

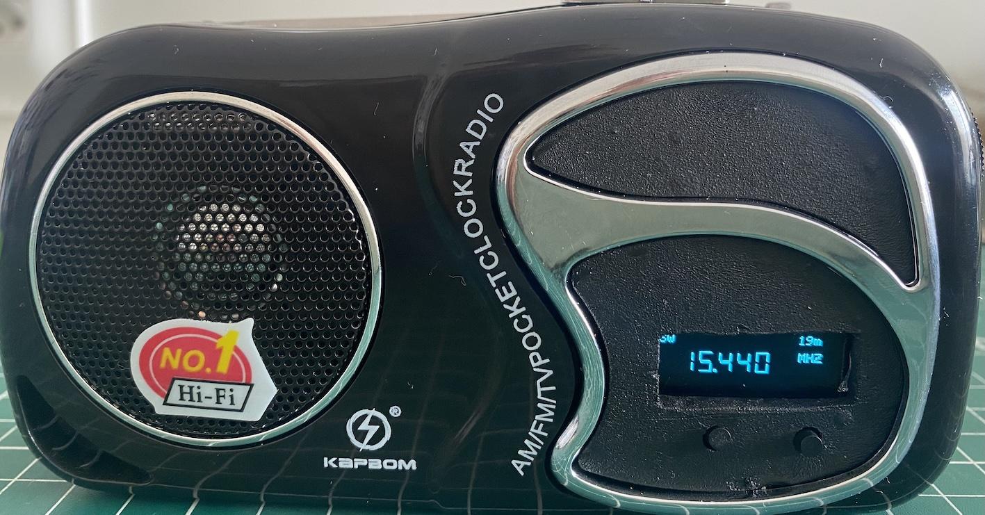
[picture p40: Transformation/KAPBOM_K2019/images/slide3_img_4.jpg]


---

## Slide 4 — Components used for the modification


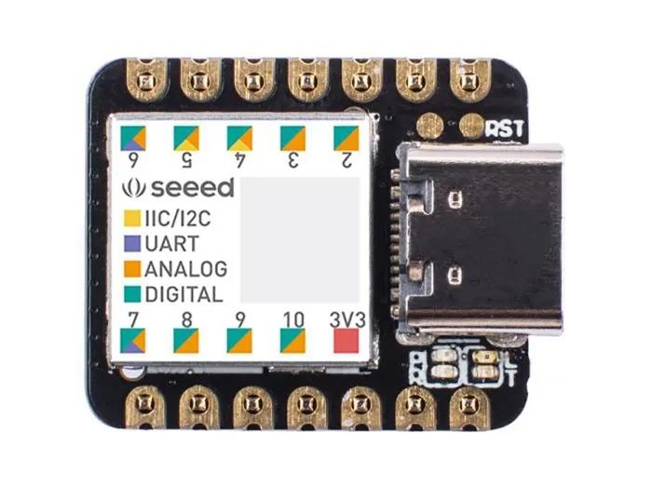
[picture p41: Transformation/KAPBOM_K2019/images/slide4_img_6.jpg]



- Seeeduino XIAO (ARM Cortex-M0+)
- OLED (I2C)
- Si4827
- Push Buttons



---

## Slide 5 — About the DSP Si4825



- Support for FM band (64–109 MHz)
- Support for AM band (504–1750 kHz)
- Support for SW band (2.3–28.5 MHz)
- No manual calibration required
- Mono audio output
- Band configuration according to region (AM/FM/SW)
- Enhanced coverage for FM/SW bands

---

## Slide 6 — About the DSP Si4827



- Support for FM band (64–109 MHz)
- Support for AM band (504–1750 kHz)
- Support for SW band (2.3–28.5 MHz)
- Selectable support for all regional AM/FM/SW bands
- Enhanced coverage of FM/SW bands
- 2-wire control interface (I2C)
- Valid station indicator
- Support for digital volume control
- Support for bass and treble adjustment

---

## Slides 7–12 — Disassembly, board, replacement, and photos

These slides show the radio opened, the board before modification, identification of the Si4825, replacement steps, and photos of the Si4827 soldered and the trace cut on pin 4 (BAND).












---

## Slide 13 — Wiring (Si4827 and Seeeduino XIAO)

| Si4827 pin | Seeeduino pin | Description |
|---|---|---|
| 1 | 2 | Seeeduino interrupt pin|
| 9 | 6 | RESET |
| 10 | A4 (SDA) | I2C bus (Data) |
| 11 | A5 (SCL) | I2C bus (Clock) |

### OLED wiring

| OLED pin | Seeeduino pin | Description |
|---|---|---|
| SDA | 4 | I2C Bus (Data)  |
| CLK | 5 | I2C Bus (Clock) |

### Push buttons wiring

| Button | Seeeduino pin | Function |
|---|---|---|
| BAND UP | 7 | Next Band |
| BAND DOWN | 8 | Previous Band  |

---

## Slide 14 — Checking the Si4827 and Seeeduino XIAO setup



---

## Slides 15–16 — Case modification





---

## Slide 17 — Finish



---

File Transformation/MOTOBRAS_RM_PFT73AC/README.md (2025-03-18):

# Converting the Motobras RM-PFT73AC Radio (Si4825) into a Digital Interface Radio (Si4827)

## About the Motobras RM-PFT73AC Radio (Original)

About the Motobras RM-PFT73AC Radio (Original)

- 7 Bands (FM, AM, and 5 SW bands)
- Analog dial
- Based on the Si4825 DSP
- Good sound quality
- Follows the classic model of old radios
- SW coverage: 62m, 49m, 31m, 25m, and 19m

## About the Modified Motobras RM-PFT73AC Radio

This radio was obtained from scrap. It is a receiver manufactured in Brazil. As seen in the image below, it arrived heavily damaged, requiring partial restoration before proceeding with the modification.

About the Modified Motobras RM-PFT73AC Radio

- 19 Bands (2 FM, 2 AM, and 15 SW)
- Analog and Digital Dial
- Based on the Si4827 DSP
- Tuned Station Indicator
- Indicator when the Analog Dial does not correspond to the current band
- Uses the same RF front-end and audio circuit as the original radio
- SW coverage: 10m - 90m (15 bands)

## Modification Steps

Fortunately, except for the audio output and control stage, the PCB was in good condition. To perform the partial restoration of the radio, it was enough to replace the volume potentiometer as well as some components near it.

### Original Radio Opened (Scrap Unit)

About the Motobras RM-PFT73AC Radio (Original)

### Motobras RM-PFT73AC Board with Si4825

Modification Steps 01 - Original Radio Opened (Scrap Unit)

### Si4825 Soldered on the Radio Board detail

Modification Steps 02 - Original Radio Opened (Scrap Unit)

### Replacement of Si4825 with Si4827

Replacement of Si4825 with Si4827

### DSP Si4825 vs. Si4827

## Components for the Modification

- **SEEEDUINO XIAO (ARM Cortex-M0+)**
  - Flash Memory: 256 KB
  - RAM: 32 KB
- **TM1637 7-Segment Display**
- **SI4827 DSP**
- **Push Buttons**
- **LEDs**

### Connections of Components with Seeeduino XIAO

## Removing the Si4825 from the Board and Modifications
- Cutting PCB traces and removing the Reset Resistor and Capacitor

## Si4827 Soldered on the Board and Connections with Seeeduino
### Si4827 Soldered on the Board and Wiring

## Finalized Modification

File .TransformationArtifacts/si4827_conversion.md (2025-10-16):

# Modificando de Si4825 para Si4827 com interface Digital

## Slide 1

### Converting a low-cost radio based on the Si4825 into a digital interface radio using the Si4827.

---

## Slide 2

### About the low-cost radio (KapBom K2019)

Two bands (MW and FM)
Less than $5
Compact and lightweight
Based on the Si4825 DSP
Sturdy plastic casing
Analog interface

Warning: There are other receivers from different manufacturers that use the same casing but are not 
equipped with the Si4825. Be sure the receiver is equipped with the Si4825.

---

## Slide 3

### About the modified radio

15 bands (3 FM, 2 AM, and 10 SW)
Bands can be configured via programming
Based on the Si4827 DSP
Uses the Seeeduino XIAO controller (ARM Cortex-M0+)

---

## Slide 4

### Components used for the modification

SEEEDUINO XIAO
ARM Cortex-M0+

OLED I2C

SI 4827

Push Buttons

---

## Slide 5

### About the DSP Si4825

Support for FM band (64–109 MHz)
Support for AM band (504–1750 kHz)
Support for SW band (2.3–28.5 MHz)
No manual calibration required
Mono audio output
Band configuration according to region (AM/FM/SW)
Enhanced coverage for FM/SW bands

---

## Slide 6

### About the  DSP Si4827

Support for FM band (64–109 MHz)
Support for AM band (504–1750 kHz)
Support for SW band (2.3–28.5 MHz)
Selectable support for all regional AM/FM/SW bands
Enhanced coverage of FM/SW bands
2-wire control interface (I2C)
Valid station indicator
Support for digital volume control
Support for bass and treble adjustment

---

## Slide 7

### Open radio (before modification)

---

## Slide 8

### Board (before modification)

---

## Slide 9

### Si4825 Identification (Check if the radio is based on Si4825)

---

## Slide 10

### Replacement of Si4825 with Si4827

---

## Slide 11

### Si4827 soldered on the board

---

## Slide 12

### Si4827 with a cut on the trace leading to pin 4 (BAND)

---

## Slide 13

### Si4827 and Seeduino XIAO wireup

| SI4827 pin | SEEEDUINO pin |  Description                |
 | ---------  | ------------  | ----------------------------|
 |    1       |  2            | SEEEDUINO interrupt pin     |
 |    9       |  6            | RESET                       |
 |   10       |  A4 (SDA)     | I2C bus (Data)              |
 |   11       |  A5 (SCL)     | I2C bus (Clock)             |
 | -----------| ------------- | ----------------------------|
 |  OLED      |               |                             |
 | -----------| ------------- | ----------------------------|
 |   SDA      |  4            | I2C Bus (Data)              |
 |   CLK      |  5            | I2C bus (CLock)             |
 | -----------| ------------- | ----------------------------|
 |Push Buttons|               |                             |
 | -----------| ------------- | ----------------------------|
 |  BAND UP   |  7            | Next Band.                  |
 |  BAND DOWN |  8            | Previous Band               |

---

## Slide 14

### Checking the Si4827 and Seeduino XIAO setup

---

## Slide 15

### Case modification

---

## Slide 16

### Case modification

---

## Slide 17

### Finish

---

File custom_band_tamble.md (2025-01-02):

| Band Name  | Narrow Frequency Range  | Wide Frequency Range |
| --- | ---| --- |
| FM3 | 87-108 MHz (75 µs) | |
| AM5 | 510-1750 kHz (10kHz) | |
| SW1 | 2.30-2.49 MHz | 2.3-10.0 MHz |
| SW4 | 4.75-5.06 MHz | 3.7-12.5 MHz |
| SW8 | 7.1-7.6 MHz | 5.9-9.50 MHz |
| SW9 | 9.2-10 MHz | 5.9-18.0 MHz |
| SW10 | 11.45-12.25 MHz | 7.0-16.0 MHz |
| SW12 | 13.4-14.2 MHz | 9.0-16.0 MHz |
| SW13 | 13.57-13.87 MHz | 9.0-22.0 MHz |
| SW14 | 15 -15.9 MHz | 9.5-18.0 MHz |
| SW16 | 17.48-17.9 MHz | 10.0-22.0 MHz |
| SW18 | 21.45-21.85 MHz | 18.0-28.5 MHz |

See Si4825 DEMO BOARD USER'S GUIDE for more details

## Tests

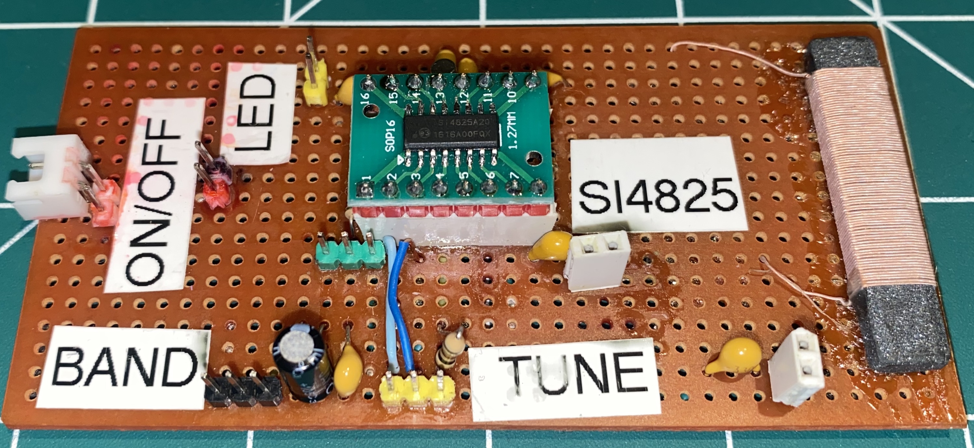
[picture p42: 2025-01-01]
Images/prototype_si4825_tester_01.jpg

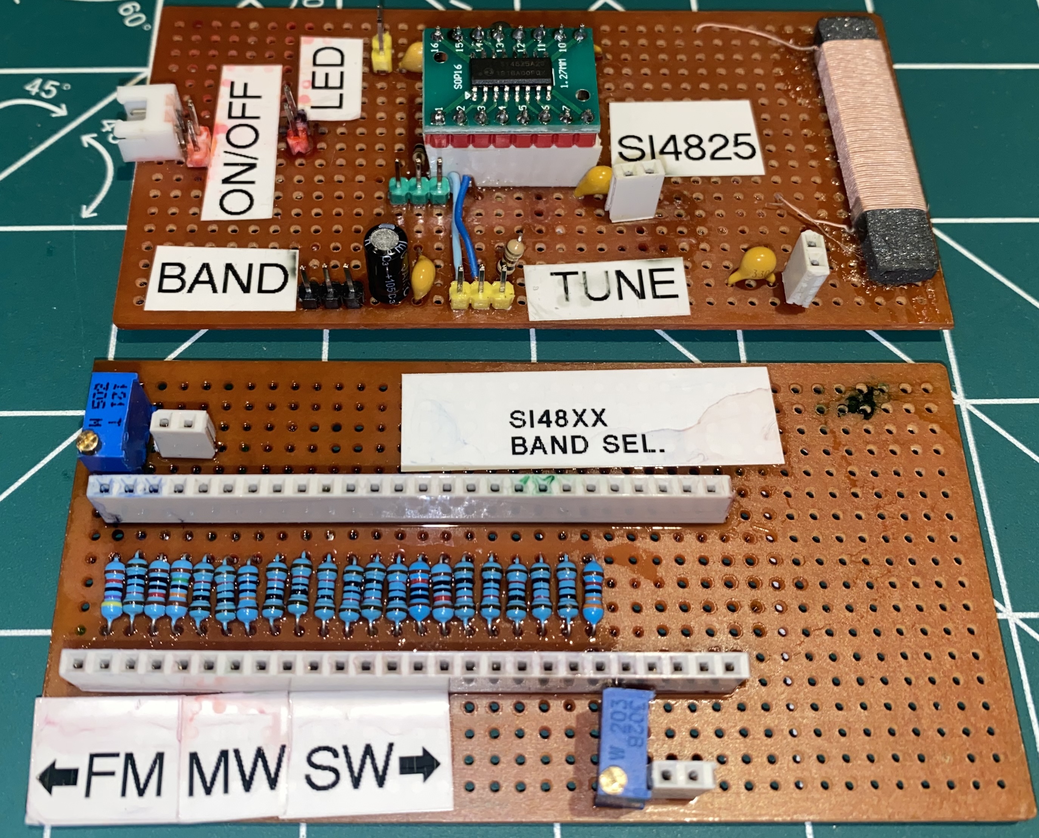
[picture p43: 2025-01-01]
Images/prototype_si4825_tester_03.jpg

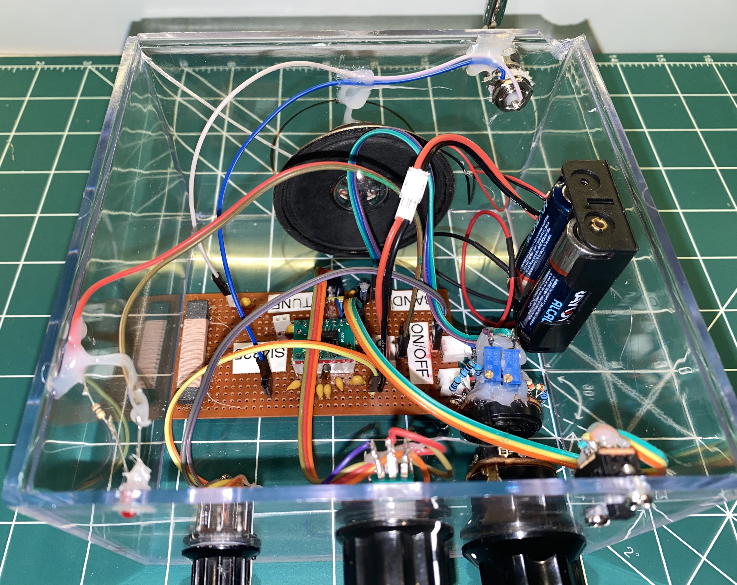
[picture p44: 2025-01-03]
Images/prototype_si4825_tester_11.jpg

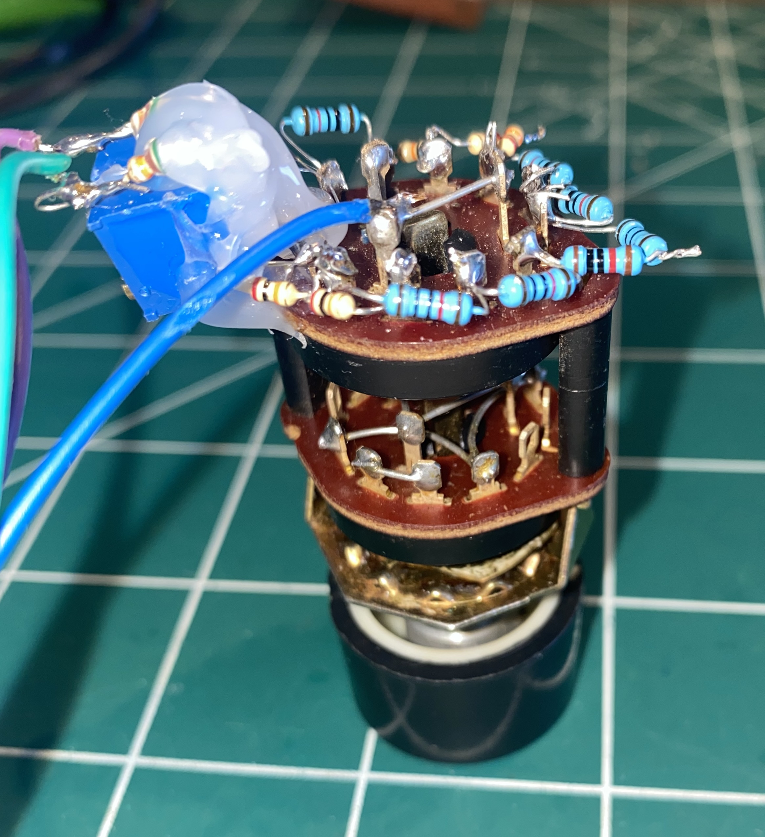
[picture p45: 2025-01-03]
Images/prototype_si4825_tester_07.jpg

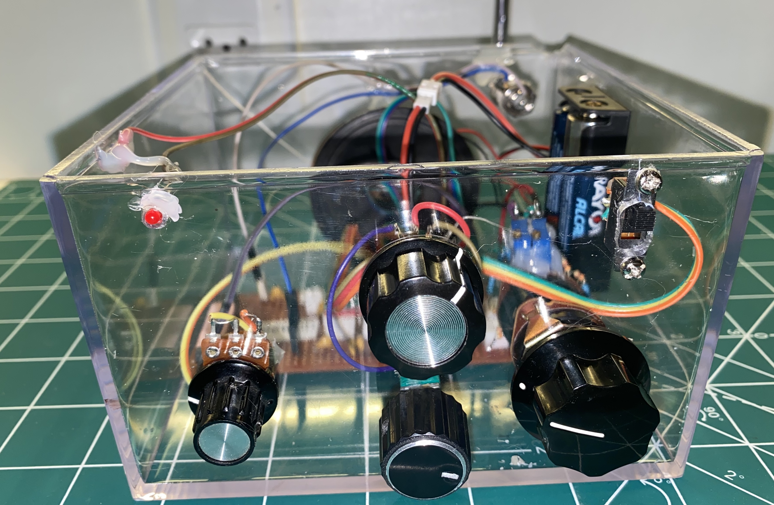
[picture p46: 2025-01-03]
Images/prototype_si4825_tester_10.jpg

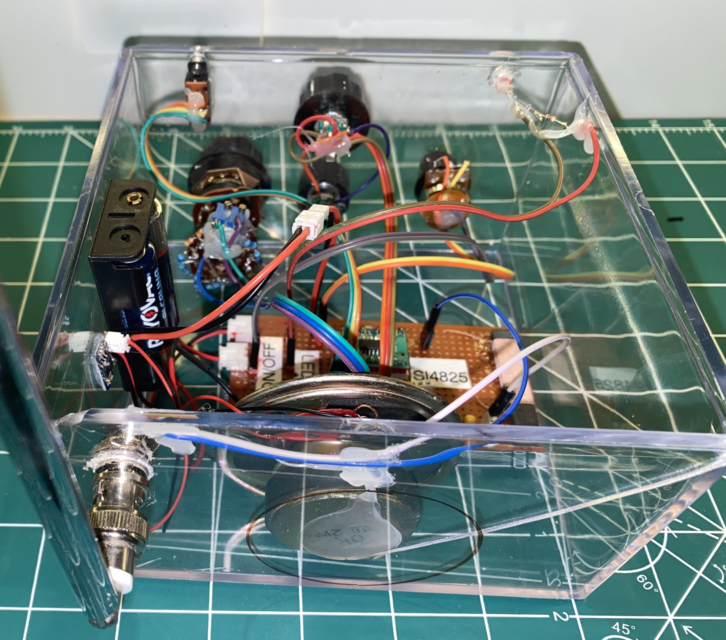
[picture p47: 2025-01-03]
Images/prototype_si4825_tester_12.jpg

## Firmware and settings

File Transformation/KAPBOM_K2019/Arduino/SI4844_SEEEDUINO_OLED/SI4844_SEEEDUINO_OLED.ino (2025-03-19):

/**
 *  This sketch runs on Seeeduino devices.
 *  I2C OLED Display and buttons Example
 *
 *  ABOUT SEEEDUINO XIAO and EEPROM
 *    The Seeeduino XIAO does no have internal EEPROM.
 *    To provide a convenient way to store and retrieve the reciver useful data, this sketch uses a library emulated-EEPROM with flash memory
 *    See FlashStorage_SAMD Arduino library on https://github.com/khoih-prog/FlashStorage_SAMD
 *

 *
 *  SEEEDUINO and SI4844 pin connections
 *
 *  | SI4844 pin | SEEEDUINO pin |  Description                                       |
 *  | ---------  | ------------  | -------------------------------------------------  |
 *  |    2       |  2            | SEEEDUINO interrupt pin                            |
 *  |   15       |  6            | RESET                                              |
 *  |   16       |  A4 (SDA)     | I2C bus (Data)                                     |
 *  |   17       |  A5 (SCL)     | I2C bus (Clock)                                    | 
 *  | -----------| ------------- | ---------------------------------------------------|
 *  |  OLED      |               |                                                    |
 *  | -----------| ------------- | ---------------------------------------------------|                        
 *  |   SDA      |  A4           | It shares the I2C bus with the SI4844              |
 *  |   CLK      |  A5           | It shares the I2C bus with the SI4844              |       
 *  | -----------| ------------- | ---------------------------------------------------|
 *  |Push Buttons|               |                                                    |                                                                     |
 *  | -----------| ------------- | ---------------------------------------------------| 
 *  |  BAND_UP   |     7         |                                                    |                          
 *  |  BAND_DOWN |     8         |                                                    | 
 *  |  VOL_UP    |     9         |                                                    | 
 *  |  VOL_DOWN  |    10         |                                                    |  
 *
 *  ATTENTION: Arduino Nano and Uno are 5V based board. Check the board voltage you are using
 *  If you are using the LGT8F328 see: https://blog.eletrogate.com/tutorial-pro-mini-evb-lgt8f328p-arduino-ide/
 

 *  Author: Ricardo Lima Caratti (PU2CLR)
 *  Oct, 2019
*/

#include <SI4844.h>
#include <Adafruit_GFX.h>
#include <Adafruit_SSD1306.h>
#include <FlashAsEEPROM_SAMD.h> // Install this library from Github: https://github.com/khoih-prog/FlashStorage_SAMD#why-do-we-need-this-flashstorage_samd-library
#include "DSEG7_Classic_Regular_21.h"



// OLED Diaplay constants
#define I2C_ADDRESS 0x3C
#define RST_PIN -1 // Define proper RST_PIN if required.

// Arduino Pin (tested on pro mini)
#define INTERRUPT_PIN 2
#define RESET_PIN 6

#define BAND_UP 7    // Next Band
#define BAND_DOWN 8  // Previous Band
#define VOL_UP 9    // Volume Volume Up
#define VOL_DOWN 10  // Volume Down

#define MIN_ELAPSED_TIME 100

// EEPROM - Stroring control variables
const uint8_t app_id = 27; // Useful to check the EEPROM content before processing useful data
const int eeprom_address = 0;

long elapsedButton = millis();

/*
  The following band table can be adjusted according to the user's preferences or local conditions. 
  Most bands on this receiver use a custom method rather than the standard SI48XX method. 
  The FM band has been divided into two bands. 
  There are two MW bands, allowing the receiver to be configured according to the regional band plan and regulations. 
  Finally, the SW bands can be modified to provide a better experience for users.
*/

typedef struct {
  int8_t bandIdx;
  uint16_t botton;    // botton frequency (10350 = 103.5Mhz; 9775 = 9,775 kHz)
  uint16_t top;       // top
  uint8_t bandSpace;  // FM only (10 = 100 kHz; 20 = 200 kHz)
  char *desc; 
} Band;

/*
  To add, remove, or modify a band, simply update the table below. Each row corresponds to a specific band. 
  Here's how the parameters are defined:

  1) First parameter: An internal value used by the SI474X to identify the band (see the Datasheet AN610 - Si48XX ATDD PROGRAMMING GUIDE page 17).
  2) Second and third parameters: These specify the lower and upper frequency limits for the band:
  3) For FM bands, the values are in MHz (e.g., 7700 means 77.00 MHz, and 10800 means 108.00 MHz).
  4) For SW bands, the values are in kHz (e.g., 4600 means 4,600 kHz or 4.6 MHz).
  5) If both frequencies are set to 0, the device will use its default internal frequencies for that band.
  6) Fourth parameter: Defines the frequency step size:
  7) For FM: 10 corresponds to 100 kHz spacing, and 20 corresponds to 200 kHz spacing.
  8) For SW: 5 corresponds to 5 kHz spacing.
  9) Fifth parameter: A descriptive name for the band, making it easier to identify.

  In the following example, except for the MW1 and MW2 bands, all bands have been customized and do not follow the SI48XX device's internal defaults. 
  Based on the datasheet "AN610 - Si48XX ATDD PROGRAMMING GUIDE" pages 17 and 18, you can select additional bands or configure them according to 
  your preferences.

  Note that in the following example, the FM bands have been configured to be narrower than those typically found in commercial receivers. 
  This approach was adopted to enhance the tuning experience. By narrowing the bands, it became easier to tune a station using a 100K potentiometer, 
  which offers only 180 degrees of rotation. Commercial receivers usually employ mechanical reduction systems, such as pulleys or gears, to improve 
  the user experience by providing finer tuning control. Since this prototype lacks such mechanical aids, I chose to narrow the bands to compensate 
  and optimize usability.

*/
Band tabBand[] = { { 3, 6400, 8800, 20, (char *) "FM0" },
                   { 3, 8700, 10100, 20, (char *) "FM1" },      
                   { 3, 10100, 10900, 20, (char *) "FM2" },
                   { 20, 0,0,0, (char *) "MW1" },             
                   { 21, 0,0,0, (char *) "MW2" }, 
                   { 25, 2300, 3200,  5, (char *) "90m"},
                   { 25, 3200, 4200,  5, (char *) "80m"},
                   { 25, 4600, 5200,  5, (char *) "60m" },
                   { 26, 5700, 6200,  5, (char *) "49m"},
                   { 27, 7100, 7600,  5, (char *) "41m"},
                   { 29, 9200, 9990,  5, (char *) "31m"},
                   { 31, 11400,12200, 5, (char *) "25m"},
                   { 33, 13400,13990, 5, (char *) "22m"},
                   { 35, 15090,15700, 5, (char *) "19m"},
                   { 38, 17400,17990, 5, (char *) "16m"},
                   { 40, 21400,21790, 5, (char *) "13m"},
                   { 40, 24890,25100, 5, (char *) "12m"},
                   { 40, 25600,26610, 5, (char *) "11m"},
                   { 40, 27000,27700, 5, (char *) "11m"},
                   { 40, 28000,28500, 5, (char *) "11m"} };

const int8_t lastBand = (sizeof tabBand / sizeof(Band)) - 1;
int8_t bandIdx = 0;



// OLED - Declaration for a SSD1306 display connected to I2C (SDA, SCL pins)
Adafruit_SSD1306 display = Adafruit_SSD1306(128, 32, &Wire);

SI4844 si4844;

void setup()
{
  pinMode(BAND_UP, INPUT_PULLUP);
  pinMode(BAND_DOWN, INPUT_PULLUP);
  pinMode(VOL_UP, INPUT_PULLUP);
  pinMode(VOL_DOWN, INPUT_PULLUP);

  delay(150); // Needed to make the OLED starts
  display.begin(SSD1306_SWITCHCAPVCC, I2C_ADDRESS); // Address 0x3C for 128x32
  display.clearDisplay();
  display.display();
  display.setTextColor(SSD1306_WHITE);

  display.setCursor(0,0);
  display.print((char *)"PU2CLR\n\nRadio experiments");
  display.display();

  // RESET EEPROM
  if (digitalRead(BAND_UP) == LOW)
  {
    EEPROM.update(eeprom_address, 0);
    display.setCursor(0,0);
    display.print((char *)"EEPROM RESET");
    delay(1500);
  }
  
  // Some crystal oscillators may need more time to stabilize. Uncomment the following line if you are experiencing issues starting the receiver.
  // si4844.setCrystalOscillatorStabilizationWaitTime(1);
  si4844.setup(RESET_PIN, INTERRUPT_PIN, -1, 100000);

  
  if (EEPROM.read(eeprom_address) == app_id)
    readAllReceiverInformation();
  else
    si4844.setVolume(60);
  

  if ( tabBand[bandIdx].botton != 0)
    si4844.setCustomBand(tabBand[bandIdx].bandIdx, tabBand[bandIdx].botton, tabBand[bandIdx].top,tabBand[bandIdx].bandSpace);
  else 
    si4844.setBand(tabBand[bandIdx].bandIdx);  


  displayDial();

}

/*
 *  writes the conrrent receiver information into the eeprom.
 *  The EEPROM.update avoid write the same data in the same memory position. It will save unnecessary recording.
 */
void saveAllReceiverInformation()
{
  EEPROM.update(eeprom_address, app_id);             // stores the app id;
  EEPROM.update(eeprom_address + 1, si4844.getVolume()); // stores the current Volume
  EEPROM.update(eeprom_address + 2, bandIdx);        // Stores the current band index
  EEPROM.commit();
}

void readAllReceiverInformation()
{
  si4844.setVolume(EEPROM.read(eeprom_address + 1)); // Gets the stored volume;
  bandIdx = EEPROM.read(eeprom_address + 2);

}

uint32_t oldFrequency = 0;
uint8_t oldStatusStationIndicator = 9;

void displayDial()
{
  String unit, freqDisplay, stereo;

  uint32_t currentFrequency = si4844.getFrequencyInteger();
  uint8_t currentStatusStationIndicator = si4844.getStatusStationIndicator() ;

  if ( oldFrequency == currentFrequency && oldStatusStationIndicator ==  currentStatusStationIndicator )
    return;

  oldFrequency = currentFrequency;
  oldStatusStationIndicator = currentStatusStationIndicator;

  if (si4844.getFrequencyInteger() > 999) 
    unit = (char *) "MHZ";
  else
    unit = (char *) "kHz";  

  display.setFont(NULL);
  display.clearDisplay();

 
  display.setCursor(3, 0);
  display.print(si4844.getBandMode());

  display.setCursor(48, 0);  
  if ( si4844.getStatusStationIndicator() != 0) 
    display.print("OK");
  else 
    display.print("  ");

  display.setCursor(105, 0);  
  display.print(tabBand[bandIdx].desc);


  display.setFont(&DSEG7_Classic_Regular_21);

  display.setCursor(16, 31);
  display.print(si4844.getFormattedFrequency(2,'.'));
  display.setCursor(104, 30);
  display.setFont(NULL);
  display.print(" ");
  display.print(unit);
  
  // It does not make sense with Si4827  -- Remove the comment if you are using the Si4844 or si4840
  /*
  if ( si4844.getStatusBandMode() == 0) {
    display.setCursor(75, 25);
    if (si4844.getStatusStereo() == 1)
      display.print("Stereo");
    else   
      display.print("Mono  ");
  }
  */

  display.display();
}

void setBand(byte cmd)
{
  if (cmd == '+')
    bandIdx = (bandIdx < lastBand) ? (bandIdx + 1) : 0;
  else
    bandIdx = (bandIdx > 0) ? (bandIdx - 1) : lastBand;

  if ( tabBand[bandIdx].botton != 0)
    si4844.setCustomBand(tabBand[bandIdx].bandIdx, tabBand[bandIdx].botton, tabBand[bandIdx].top,tabBand[bandIdx].bandSpace);
  else 
    si4844.setBand(tabBand[bandIdx].bandIdx);  

  saveAllReceiverInformation();
  elapsedButton = millis();

}

void setVolume( char v) {
  si4844.changeVolume(v);
  elapsedButton = millis();
}

void loop()
{
  if ( (millis() - elapsedButton) > MIN_ELAPSED_TIME ) {
    // check if some button is pressed
    if (digitalRead(BAND_UP) == LOW )
      setBand('+'); // goes to the next band. 
    else if (digitalRead(BAND_DOWN) == LOW )
      setBand('-'); // goes to the previous band. 
    else if (digitalRead(VOL_UP) == LOW )
      setVolume('+');
    else if (digitalRead(VOL_DOWN) == LOW )
      setVolume('-');
  }

  if (si4844.hasStatusChanged())
    displayDial();
  
  delay(10);
}
